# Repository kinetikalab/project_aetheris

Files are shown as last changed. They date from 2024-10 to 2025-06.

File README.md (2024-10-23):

# Project Aetheris
Open source project for plasma water purification

# Water Purification Plasma Chemistry 101

Plasma water purification and activation is a well-known process based on the generation of Reactive Oxygen and Nitrogen Species (RONS) in a plasma discharge, which subsequently oxidize organic impurities and degrade pathogens in water.

## Key Reactions

The basic concept of plasma purification involves the generation of highly reactive species that oxidize organic pollutants and destroy pathogens. Oxidative purification is not a novel concept; it is a well-established technique in water treatment. For example, ozonation and chlorination are well-known oxidative processes used in the water purification industry. While ozone and chlorine are relatively stable, their oxidation potential is limited precisely because of their stability.

In gas discharges, short-lived radicals with excellent oxidation potential can be generated. These radicals are rarely found in nature due to their high reactivity, which results in very short lifespans—on the order of milliseconds or even less.

The hydroxyl radical (OH) has one of the highest oxidation potentials, second only to fluorine, but fortunately, it does not produce toxic by-products. The hydroxyl radical is the most significant species in plasma chemistry, actively oxidizing pollutants and destroying pathogens, and serving as a precursor to other powerful oxygen and nitrogen radicals.

In designing plasma-based water purification technology, we optimized the production of hydroxyl radicals to enhance the efficiency of pollutant oxidation and pathogen destruction.

The hydroxyl radical (OH) plays a critical role in this process. In the literature, the following reaction is often mentioned:

`e + H2O -> OH + H`

However, this reaction requires electron energies greater than **9 eV**, which are rare in atmospheric-pressure gas discharges in air. Additionally, this is a slow reaction. A more efficient way to generate OH is through the following reaction involving excited atomic oxygen:

`e + O2 -> O(1D) + O(3P)`

`H2O + O(1D) -> OH + OH`

`O2 + O(1D) -> O2 + O`

`N2 + O(1D) -> N2 + O`

The dissociation of O₂ is much faster than that of H₂O. After O(1D) is formed, it is a highly reactive species that most likely reacts with N₂, O₂, or H₂O. The balance between H₂O, O₂, and N₂ depends on their concentrations. In dry, cold air, about 90% of O(1D) is lost due to relaxation with N₂ and O₂, but in hot, humid air, around 20% of O(1D) is lost due to relaxation.

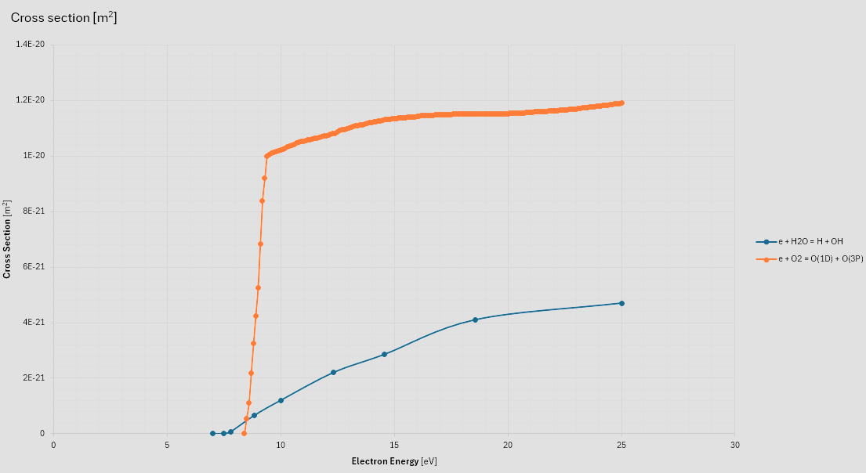
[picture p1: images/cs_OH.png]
Reactions cress sections - **Morgan (Kinema Research & Software)** database and **IST-Lisbon** database, www.lxcat.net, retrieved on Aug 3, 2024.


These reactions are well understood, but the importance of igniting plasma in warm, humid air is often not clearly emphasized in the literature.

## Ozone's Role in Plasma Chemistry

Another critical factor is the presence of ozone (O₃), as it prolongs the lifespan of OH through well-known atmospheric chemistry cycles involving ozone destruction:

`OH + O3 -> O2 + HO2`

`HO2 + O3 -> OH + 2O2`

While these reactions are not particularly fast, ozone is a relative stable molecule and can accumulate in the discharge chamber, reaching high concentrations. Furthermore, HO₂ is a reactive radical that easily dissolves in water, generating hydroxyl radicals in the liquid phase. It plays a significant role in Advanced Oxidation Processes (AOPs) in water.

One crucial aspect that needs attention is the accumulation of NO₂⁻ and NO₃⁻ ions in water treated with plasma. The cyclic synthesis and breakdown of peroxynitrite, with a residual tail of these ions, seems to be a plausible explanation for the phenomenon of Plasma Activated Water (PAW). A more detailed discussion of the synthesis of nitrogen compounds in plasma discharge in water can be found [here](https://onlinelibrary.wiley.com/doi/abs/10.1002/ppap.202000058)

While in some applications—such as sterilization and disinfection in medicine or accelerating plant growth—this fact is a significant advantage, for the production of high-quality drinking water, nitrogen compounds are unacceptable. Therefore, reducing nitrogen concentration is necessary not only to increase ozone levels but also to eliminate residual nitrates and nitrites from the water. However, if we use this technology and reactor for producing water for agriculture, the oxygen filter must be removed from the design.

**Too simple for you?** You can [read more](/discharge_model/glinding_arc_in_ejector_flow.pdf) in the discharge model documentation, where the concept is discussed in greater detail

## In Summary

An ozone-hydroxyl mixture in highly humid air is an excellent combination for mixing with contaminated water.

# Basic Design Principles

1. **Separation of Plasma and Water**  
   It is not necessary to treat contaminated water by directly applying plasma to its surface. This approach is inefficient and difficult to scale. Instead, we generate the ozone-hydroxyl mixture separately and mix it with the water.

2. **Discharge Chamber Design**  
   The most effective method is to feed the discharge chamber with humidified air, then mix the activated air-vapor mixture with the water. An ejector system seems to be the most efficient way to achieve this.

3. **Oxygen and Nitrogen Control**  
   Since ozone is required for higher efficiency, a circulation system during the treatment process is essential. Alternatively, nitrogen should be removed from the water tank at the beginning of the treatment process for better results.

# Overall Device Design

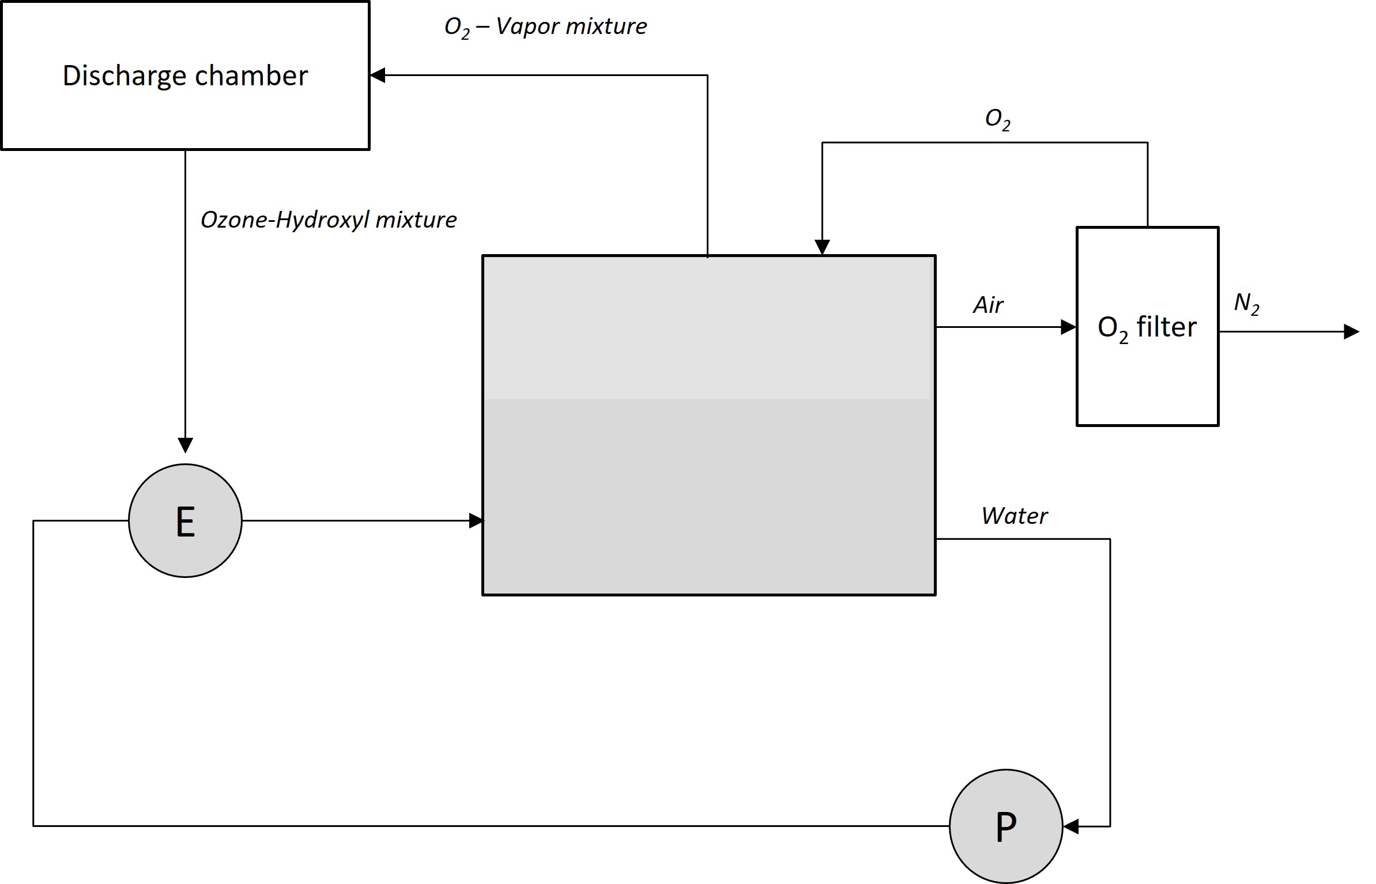
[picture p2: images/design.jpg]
Schematic Design


- **Power Electronics**: See the [power_electronics](./power_electronics/).
- **Discharge Chamber**: See the [discharge_chambers](./discharge_chambers/).
- **Ejector (E)**: For simple ejector models and mixing system dimensions, refer to the [ejector_model](./ejector_model/). Note: the ejector is often combined with the discharge chamber, but these models provide key inputs for the mixing system design.
- **O₂ Filter**: A standard O₂ concentrator with molecular sieves.
  
**Important** Please, read [issues](https://github.com/kinetikalab/project_aetheris/issues) before trying to repeat the design.

# Additional information
2-dimentional gas dicharge model (С parallel code) with plasma-fluid drift-diffusion approximation here [discharge_model](./discharge_model/)

Experimental results are [here](/results) - to be updaded soon (interesting results are coming soon)

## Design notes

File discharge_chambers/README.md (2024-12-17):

# Description

Different designs of discharge chambers:

- [surface_barrier_discharge](./surface_barrier_discharge/): Surface barrier discharge with a spiral electrode.
- [barrier_discharge](./barrier_discharge/): Classical barrier discharge with a set of rods.
- [glinding_arc](./glinding_arc/): Gliding arc ignition in ejector flow
  
- [3d_rotaing_gliding_arc](./glinding_arc/): **FIRST DRAFT** Gliding arc with magnetic rotation, the most promising option.
  
  A couple of words about the rotating arc. Although the rotation of a discharge arc in a magnetic field is not a novel idea, it is quite a cool concept, and here’s why. Achieving uniform plasma in a relatively large volume at atmospheric pressure is the Holy Grail of plasma engineering. Despite the fact that we can't ignite plasma throughout the entire volume, we can force the arc to rotate at a relatively high speed (on the order of kilohertz) and ensure uniform radical generation within the entire discharge chamber. Uniform radical generation leads to excellent mixing with contaminated water, resulting in greater purification efficiency.

- [double_surface_dicharge](./double_surface_discharge/): **Another promising option:** A two-sided surface discharge. Air is drawn through the connection, passing through the outer electrode (a mesh) and then into the ejector chamber where the inner electrode is located. This allows for a two-step activation process, utilizing the full energy of the surface discharge.

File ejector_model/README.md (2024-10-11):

# Ejector model

Sipmle ejector model in based on Sokolov-Zinger model *Sokolov E.Ya. Jet-Stream Apparatuses. Sokolov E.Ya., Zinger N.M. Energoatomizdat, 1968*

Here is the dimentions
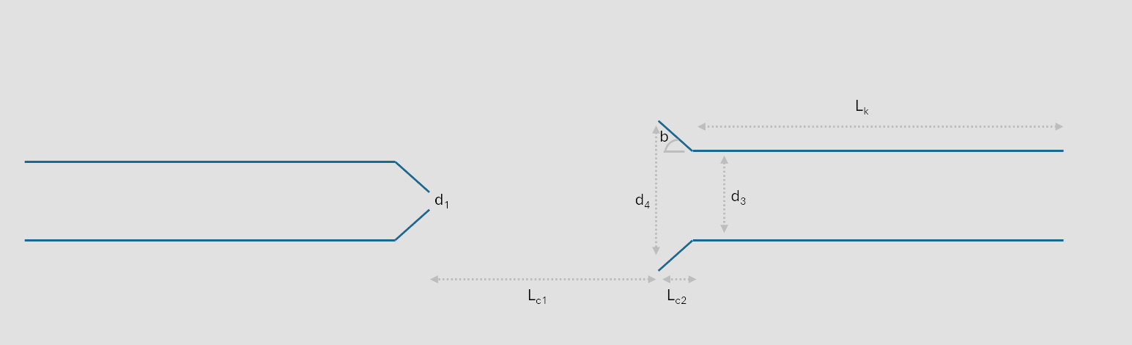
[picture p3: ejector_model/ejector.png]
Ejector dimentions


## Python script
Use python `ejector_model.py` script for dimentions calculations

## Comments

**Designing an ejector (mixing) system involves optimizing two key parameters:**

1. **Air/Water volume ratio** – A higher ratio is better.
2. **Pressure in the discharge chamber** – Lower pressure improves discharge.

However, these two parameters contradict each other, so finding the right balance is the challenge.

**Current Setup:**
- Pressure in the discharge chamber: ~0.5 bar
- Pump: 7-8 bar / 10 L/min – It’s really not easy to find a high-quality pump that can meet these specifications.
- Air/Water volume ratio: 2-3

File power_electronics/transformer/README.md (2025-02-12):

# Description

Design of a high-voltage resonant transformer (L1-L2). See the equivalent circuit diagram in [equivalent_circuit](/power_electronics/equivalent_circuit).

The current coupling coefficient achieved is **k = 0.99**.

- **Secondary winding parasitic capacitance:** 11 pF  
- **Interwinding parasitic capacitance:** 10 pF  

## Design

### Materials Needed

1. Nanocrystal core: [T60006-L2090-W518 Vacuumschmelze](https://eu.mouser.com/ProductDetail/Vacuumschmelze/T60006-L2090-W518?qs=ePbE9GiMmvUhadR4ky1MIg%3D%3D)
2. Coated copper wire: [0.3 mm](https://www.amazon.de/-/en/dp/B09VP9QQGW?ref=ppx_yo2ov_dt_b_fed_asin_title)
3. Housing: [CAD model](/power_electronics/transformer/High-Voltage_Transformer.f3d)
4. Potting compound 
5. Litz wire for primary windings (I used 3x20x0.2 mm wire)

### Process
See transformer design [CAD Model](/power_electronics/transformer/High-Voltage_Transformer.f3d)

**Insulation of the core**

1. Put core intto filling form (do no forget add silcon overaly)
2. Fill the form with potting compound and wait until it cure. 
It is important to avoid core breakdown.

**Secondary windings**

4. Wind the secondary winding using 0.3 mm coated wire, approximately 130 turns.  
   **IMPORTANT:** Maintain a spacing of ~0.2–0.3 mm between turns to minimize parasitic capacitance.
5. Fill the seondary winding with potting compound and wait until it cure.

**Primary windings**

6. Wind 3 primary windings. Refer to the provided 3D model for detailed instructions.

## Comments

1. The T60006-L2090-W518 core is used because it has very low losses and ensures exceptional magnetic permeability. This allows for **fewer turns**, which reduces parasitic capacitance.
2. Litz wire, or even a bundle of Litz wires, is essential due to the high current in the primary windings. It minimizes the skin effect and improves efficiency.
3. Potting compound is critical for insulation to prevent breakdowns between the secondary and primary windings or core breakdown.

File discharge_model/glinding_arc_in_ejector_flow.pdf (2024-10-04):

# GLIDING ARC DISCHARGE MODEL IN EJECTOR FLOW

## Table of Contents

## Problem Statement

We are developing a two-dimensional model of a low-temperature gas discharge powered by a resonant H-bridge.

Several key assumptions are made for this model:

1. The potential difference between the electrodes changes significantly more slowly than the characteristic time for a substantial change in electron energy.
2. The characteristic spatial scale of field variation is much larger than the mean free path of an electron (except within the cathode layer).

These assumptions allow us to assert that the electron energy distribution function depends on the local electromagnetic field, and thus we can employ the drift-diffusion approximation. While this approximation is not valid within the cathode layer, it is fully applicable in the rest of the spatial domain.

The task is reduced to solving the plasma hydrodynamic equations along with Poisson's equation, subject to given boundary conditions.

In the literature on gas discharge modeling, researchers often focus on one specific aspect— either solving the Boltzmann equations under certain approximations or studying and approximating the voltage-current characteristics of the discharge. This specialization, while useful for advancing particular areas of study, often creates a disconnect between the fundamental physics and the practical implementation of discharge systems.

For an engineer or a researcher working on practical solutions, bridging these two domains can be challenging. Understanding how to integrate both the fundamental theoretical aspects and the applied electrical characteristics is crucial for effective system design. In this document, we aim to guide the reader through the complete process of designing and calculating a discharge chamber from the ground up. We will break down each stage step-by-step, from designing and calculating the power circuit to directly modeling the gas discharge itself.

Our goal is to provide a holistic view that connects the theoretical underpinnings with practical engineering decisions, offering an accessible pathway for those looking to combine both aspects in their work.

## Power Supply Configuration

The model assumes a power supply based on a resonant H-bridge circuit (an equivalent circuit is provided here). (https://github.com/kinetikalab/project_aetheris/tree/main/power_electronics/equivalent_circuit)

From a modeling perspective, it is more convenient to work with the T-equivalent circuit of the transformer rather than the transformer itself. The equivalent circuit is shown in Figure 1.

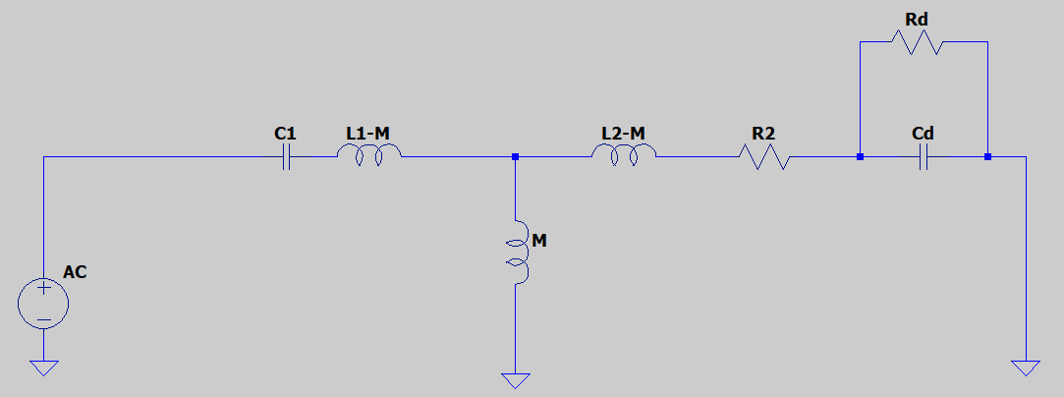
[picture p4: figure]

Figure 1. T-equivalent circuit
M = k√L1L2 – Mutual inductance, with k – being the coupling coefficient, which depends on the coil design.

The coupling coefficient, k, is considered known. In practice, for high-voltage high-frequency transformers, values of k around 0.5 to 0.6 can be easily achieved. Example of high-frequency resonant power transformer can be found here. (https://github.com/kinetikalab/project_aetheris/tree/main/power_electronics/transformer)

It is technically extremely challenging to build a high-voltage transformer with a turns ratio in the hundreds or thousands. Therefore, it is more convenient to work with a resonant circuit, which increases the voltage between the electrodes through both resonance and the turns ratio.

### Resonance Parameter Calculation

Im (Z) = 0 | (1)

where Z – complex impedance

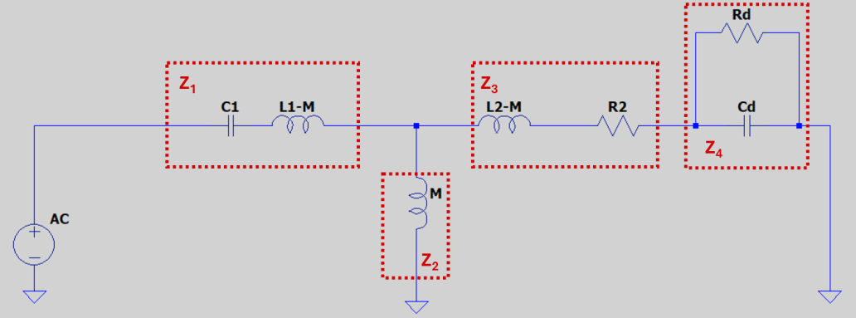
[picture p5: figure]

Z = Z1 +

Z2 ∙ (Z3 + Z4

)
Z2 + Z3 + Z4

Z1 = −

i
ωC1

+ iω(L1 − M)

Z2 = iωM

Z3 = R2 + iω(L2 − M)

Z4 =

−Rd ∙

i
ωCd

⁄
Rd − i
ωCd

⁄

An analytical expression for Z can be derived, but the resulting formulas are quite cumbersome. As can be seen, all parameters are known except for Rd. The resistance of the discharge gap depends on the applied voltage, ranging from infinity (when there is no breakdown) to nearly zero when the discharge transitions to an arc.

To begin, we will analyze the behavior of the circuit under no-load conditions, i.e., in the absence of discharge, where Rd = ∞. Our primary interest is the quality factor Q of the resonant circuit, which indicates how much the voltage is amplified at resonance. By knowing Q, we can easily estimate the amplitude of the voltage across the discharge gap Ud.

Ud = U0 ∙ Q ∙ k ∙ N

Где N = √
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
ω = 2πf, f – switching frequency of the keys (transistors).

Figure 2 shows the result of the quality factor calculation for the following parameters (I have conducted the initial measurements of the future coil and know its characteristics):

C1 = 50 nF

L1 = 1.531 uH

L2 = 1,522 uH

R2 = 0.12 Oℎ

Cd = 1.6 pF

Rd = ∞ Oℎ

k = 0.5

It is customary to express the quality factor in decibels.

Q [db] = 20 ∙ log10Q

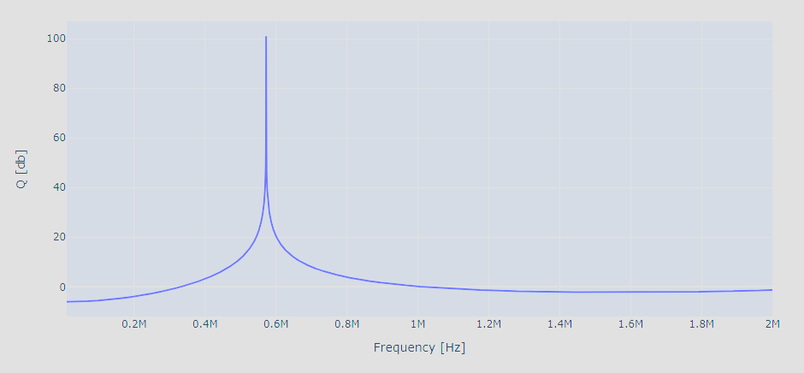
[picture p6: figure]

Fig 2. Quality factor modeling.

The resonant frequencies for the given discharge chamber and coil parameters can be controlled using the balancing capacitor C1. By adjusting C1 it is possible to shift the resonant frequencies to the left or right.

Next, let's examine how Rd affects the behavior of the circuit. Suppose we are operating at the first resonant frequency f1 = 572 kHz. We will analyze how the quality factor depends on Rd.

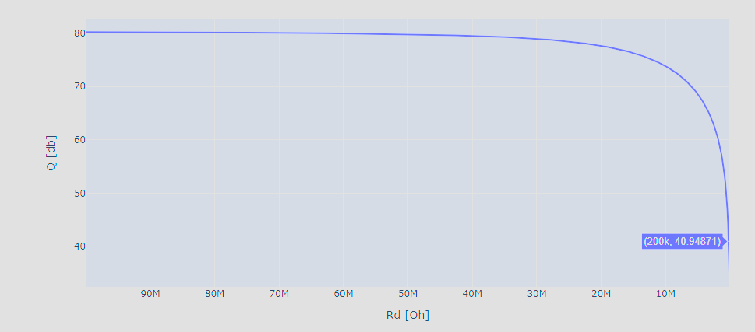
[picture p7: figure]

Fig 3. The dependence of the quality factor at the first resonant frequency on the resistance of the discharge gap.

As can be seen, the quality factor starts to drop significantly only when the resistance is below 10 MΩ, and, for example, at a resistance of ~200 kΩ, it reaches approximately 40 dB (which corresponds to a voltage amplification of ~100 times).

Now, let's try to determine the steady-state active voltage across the discharge gap.

A typical voltage-current characteristic of the gas discharge is shown in Figure 4.

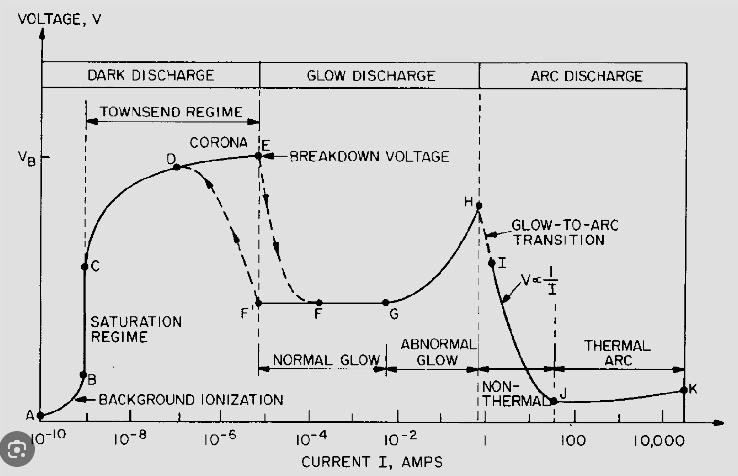
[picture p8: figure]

Figure 4. Qualitative voltage-current characteristic of the gas discharge

At low voltage, the current through the discharge gap is zero. As the breakdown voltage is reached (triggering the electron avalanche), a corona discharge ignites first, which then transitions to a glow discharge, and eventually to an arc. At this point, the resistance drops to very low values, and the discharge can be maintained with relatively low external voltage. This occurs when an arc forms in a localized area, making further spatial propagation of the discharge impossible, as it stabilizes in this narrow spatial zone, and resonant processes are no longer needed to sustain it.

We see that it is not necessary to apply a voltage between the electrodes much higher than the breakdown voltage. This is a crucial observation, as once the breakdown voltage is reached, all the power from the source is used to increase the current (i.e., to sustain and grow the electron avalanche).

In other words, we should maintain the voltage between the electrodes close to the breakdown voltage most of the time.

Consider a discharge chamber with a breakdown voltage of about 15 kV. Geometrically, this corresponds to approximately 5 mm between the electrodes (which is roughly typical setup). Since we want the voltage to exceed the breakdown voltage for most of the period, we will set a target amplitude of 30 kV.

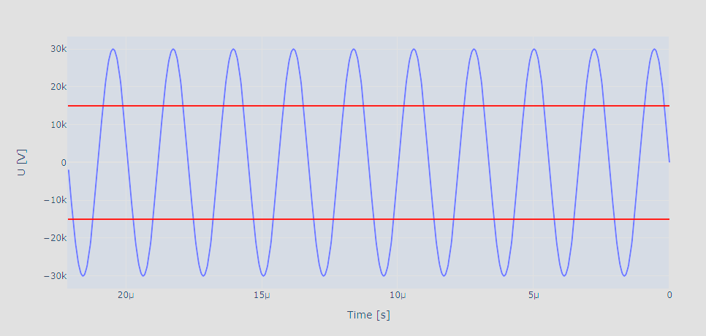
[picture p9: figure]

Assume that the power of the DC source is known and is approximately 500 watts (again, typical for small experimental setups). Let us also assume that other circuit losses are negligible, and all the power from the source is used to sustain the discharge.

P =

Ud

2

2Rd

Thus, the resistance Rd ≈ 200 kΩ, and as can be seen from Figure 3, the quality factor remains high even at this resistance, with the current through the discharge gap being approximately 30-40 mA.

In other words, we observe that under power limitation and high breakdown voltage conditions (tens of kilovolts), the discharge behavior does not affect the resonant frequencies, provided that the discharge does not transition to an arc. If the discharge transitions to an arc, high voltage is no longer required to sustain it, and even a detuning from resonance with a drop in voltage to the hundreds of volts range would be sufficient to maintain the arc.

In practice, this means that the DC source amplitude and the geometry of the discharge gap should be chosen such that:

1. The voltage between the electrodes exceeds the breakdown voltage for most of the period.
2. The discharge chamber design prevents the formation of a stable but geometrically small arc.

If both of these conditions are met, the discharge gap will still have a significant resistance, ensuring that it does not affect the resonant processes of the power circuit.

Let's take a moment to reflect on this point. We have significantly simplified the model by removing the feedback loop between the power electronics and the discharge model. We also recognized the importance of preventing the discharge from transitioning to a stable arc, which can be sustained with relatively low power but is, due to its limited geometry, largely useless for our purposes.

## Discharge Model

Before proceeding to the plasma equations, it is necessary to formulate the problem and clarify some important parameters.

We are modeling a gliding arc discharge. The overall design of the device is shown in Figure 5.

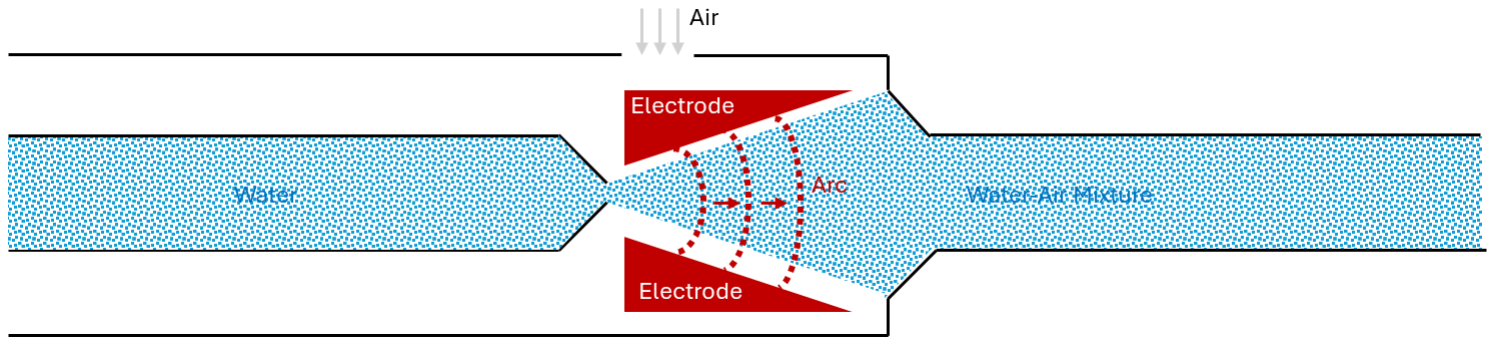
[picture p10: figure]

Figure 5. Gliding Arc in Ejector Flow
Water under pressure pp enters through the ejector nozzle, and due to the narrowing of the nozzle, the water flow velocity increases, creating a region of reduced pressure in the discharge chamber pn, after which it exits into the external environment at pressure pc
. Due to the pressure
difference, air is drawn into the discharge chamber and mixes with the water in a volume ratio of air-to-water ψ . This is a classical water-air ejector setup. All parameters pp, pc

, pn, ψ are
considered known. For details, see ejector model. (https://github.com/kinetikalab/project_aetheris/tree/main/ejector_model)

At the nozzle exit, two electrodes are positioned, supplied with power from the circuit described in the previous chapter. The electrodes are designed in a diverging geometry, meaning the distance between them increases as one moves away from the ejector nozzle.

A few words about the gliding arc discharge:

The gliding arc discharge forms in a system of diverging electrodes. The arc ignites at the narrowest point and moves slowly (at a rate comparable to the medium's velocity) into the expansion zone of the gap between the electrodes (i.e., from left to right in Figure 5). At a certain distance, where the field strength is insufficient to sustain the discharge, the arc extinguishes. Thus, the arc seems to glide between the electrodes in the direction of the medium's flow. Importantly, a gliding discharge only occurs in a moving medium. This means that if the medium between the electrodes is stationary, a gliding discharge will not occur, and we will observe a stationary arc at the point of minimum distance between the electrodes. The mechanism behind the arc's gliding behavior is not fully understood, but it likely involves two factors:

1. The moving medium "disrupts" the stationary arc, imparting some velocity to the electrons and ions in the direction of the medium's movement.
2. The electrode geometry creates a potential gradient in the direction of the electrode divergence.

In other words, we are modeling a discharge in a moving medium consisting of oxygen molecules, nitrogen, vapor, and macro-particles (droplets) of liquid water.

Let's consider the main classes of particles:

1. Electrons
2. Positive ions of oxygen, nitrogen, and water
3. Negative ions of oxygen and water, formed through electron attachment reactions
4. Neutral molecules of oxygen, nitrogen, and water
5. Macro-particles of liquid water

There are practical engineering implementations of water spray into the discharge zone. However, it is important to note that the above setup is quite different from typical spraying. We are dealing with a continuous ejector jet, which, at some distance from the nozzle, begins to break into large droplets due to airflow and turbulent effects. Therefore, we have a medium consisting of very humid air and large (0.5-1 mm in diameter) water droplets in the jet.

Points 1-4 are more or less straightforward and are considered in all hydrodynamic plasma models, so we will focus particularly on the macro-particles of water.

### Influence of Water Droplets

Consider a water droplet of radius rd moving at velocity ug in a medium with concentrations and average energies of electrons and ions, ne

, ε̅e and ni

, ε̅i
, respectively. Let us analyze the processes of absorption and scattering of charged particles by the droplet.

Concentration of Water Droplets and Medium Velocity

Next, we derive the velocity of the medium and the concentration of water molecules. We assume that the volumetric mixing coefficient of air and water ψ , the saturated vapor pressure ps
, the
pressure inside the discharge chamber pn, and the temperature inside the chamber T, are known.

The mass of water in the discharge chamber is given by ρV
1+ψ

, where ρ is the density of water,

and is the V volume of the discharge chamber.

On the other hand, the mass of water in the discharge chamber is equal to the sum of the mass of liquid water droplets and the mass of water in vapor form.

ρV
1+ψ

=

Aw
NA

⏞

Mass of
water molecule
∙

psV
kbT

⏞

Number of
vapor molecules

+ N⏞d Number of droplets

∙

ρVd
Aw

NA

⏞

Number of
molecules
in one drop
Aw
NA

⏞

Mass of
water molecule

NA – Avogadro constant

Vd =

4
3

πrd

3 – water drop volume

From this equation, the concentration of water droplets can be determined.

nd =

Nd
V

=

1
Vd(1+ψ)

−

psAw
NAkbT

1
ρVd

(1)

The concentration of vapor molecules is calculated using the ideal gas equation of state.

ns =

ps
kbT

(2)

Concentration of oxygen and nitrogen molecules

nO2 = 0.21 ∙

pn−ps
kbT

(3)

nN2 = 0.79 ∙

pn−ps
kbT

(4)

Now, let's consider the overall flow pattern of the jet.

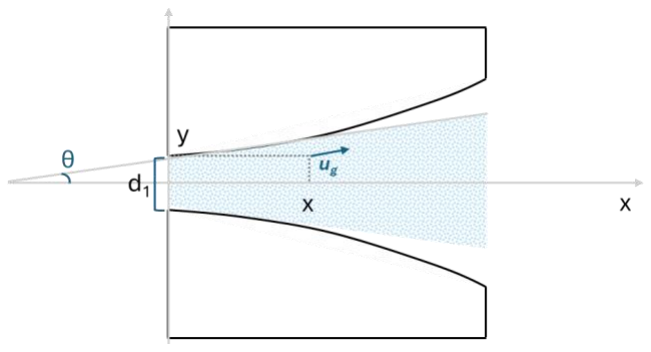
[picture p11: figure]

Fig 6. Ejector water flow

[TBD] Provide a particular solution of the Navier-Stokes equation for a free laminar jet.

Absorption of Electrons and Ions by Water Droplets

A droplet absorbs electrons and ions, acquiring a certain charge. The charge cannot be infinite, as a negatively charged droplet, for instance, will begin to repel electrons and attract ions. The equilibrium charge can be estimated by balancing the fluxes of electrons and ions onto the droplet's surface. We will disregard quantum mechanical tunneling effects and consider a classical approximation. Additionally, we assume that the electron energy distribution follows Maxwellian statistics. In a gas discharge, this is generally not true, but for estimating the droplet charge, the Maxwellian assumption provides acceptable accuracy.

Number of electron absorptions of the drop per unit time:

dNe

d
dt

= ne

- θe

̅̅ ∙ πrd
2
- (1 −

e∙φd
ε̅̅e̅

) e

−

eφd
̅ε̅e̅

⁄

, where υ̅e = √
2ε̅̅e̅
me

– average electron velocity (5)

Let's go through the formula in detail:

ne

- υ̅e

the electron flux multiplied by the absorption cross-section πrd

2

- (1 −

eφd
ε̅̅e̅

), which equals

the droplet's surface area multiplied by the probability of overcoming the Coulomb barrier (1 −

eφd
ε̅̅e̅

),. φd here, is the potential on the droplet surface, and e

−

eφd
ε̅̅e̅

⁄
represents the fraction

of electrons that have energy greater than the Coulomb barrier.

The number of positive ion absorptions by the droplet per unit time:

dNi

d

dt

= ni

- θi

̅ ∙ πrd
2
- (1 +

e∙φd
ε̅i

)

Since ions are attracted to the negatively charged droplet, the sign in the coefficient for overcoming the barrier is reversed, and the Maxwellian distribution exponent is absent.

Let us find the equilibrium potential φd, assuming quasi-neutral plasma where ni = ne .

dNi

d

dt

=

dNe

d
dt
Omitting the mathematical derivation under the assumption that ε̅e ≫ ε̅i and mi ≫ me :

eφd
ε̅̅e̅

~ 1 − e ∙

√
ε̅̅e̅
ε̅i
√
mi
me

⁄ ~1

In other words, the equilibrium potential on the droplet accumulates a very large charge, effectively blocking further electron flux onto the droplet surface due to Coulomb repulsion. Such a result is evident even from simple considerations without requiring mathematical calculations. The average velocity of electrons in non-equilibrium plasma is orders of magnitude higher than that of ions, and therefore, to "balance" the difference in fluxes, the droplet must accumulate a very large charge.

Now, let us estimate how much time is required to reach this equilibrium. Let us return to equation (5).

The potential of the droplet can be expressed in terms of the number of absorbed electrons.

φd =

1
4πε0

Ne

de
rd

Then

dNe

d
dt

= ne

- θe

̅̅ ∙ πrd
2
- (1 −

1
4πε0

Ne

de

2
rdε̅̅e̅

) e

−

1
4πε0

Ne

de
2
rdε̅e̅
(6)

Integrating equation (6) from 0 to Ne

d
(maximum possible charge of the droplet):

Ne

d = Neq

d
- ς, где Neq

d =

4πε0rdε̅̅e̅
e

2

, ς = 1 − e ∙

√
ε̅e̅
εi

̅̅
√
mi
me

We obtain the time required for the droplet to absorb the maximum possible charge.

t = τs ∫

e

u
1−u

du ς
0

, τs =

1
ne∙√
2ε̅e̅
me

∙πrd

2

(7)

Unfortunately, integral (7) can only be solved numerically. To proceed, we will substitute typical energy and concentration values for the gas discharge.

εe
εi

~ 50, εe~ 4 эВ,

mi
me

~ 60 000 (O2 or N2 ions), rd~800 um, ε̅e~ 4 eV

We obtain t~10⁻¹⁹s, which means that a water droplet, upon entering the active discharge zone, absorbs a large charge almost instantaneously, and the absorption cross-section of the droplet can be calculated using the formula:

σd

e−att(εe
, ε̅e

) ≈ πrd

2

- [1 −

ε̅̅e̅
εe

], εe > ε̅e
(8a)

For ions:

σd

i−att(εi
, ε̅e

) ≈ πrd

2

- [1 +

ε̅̅e̅
εi
] | (8b)

For ions, we can directly calculate the average absorption frequency by droplets, assuming a Maxwellian distribution function.

νd

i−att ≈ 2 ∙ rd

2

- √
π
kbTimi
- ε̅e
| (8c)

Elastic Scattering by Water Droplets

Elastic scattering of charges in plasma is derived using Rutherford's formula

σd

el(εe) = 4π ∙ (

Ne

de

2
4πε02εe

)

2
lnΛ | (9)

lnΛ here, is the Coulomb logarithm, obtained by integrating Rutherford's formula over scattering angles related to Debye and Coulomb radii. Generally, without going into details, for plasma it can be considered a dimensionless constant approximately equal to 10-12

Substituting the maximum possible charge into (10), we get:

σd

att = πrd

2

(

ε̅̅e̅
εe

)

2
lnΛ | (10)

Below, we will show that elastic scattering by droplets plays no significant role.

### Collision Integral

Important Note: Below, I break down the simplification of the Boltzmann collision integral step-by-step by integrating it over momentums. There is nothing particularly novel or noteworthy here — this is an entirely standard technique described in all plasma physics textbooks. Anyone who has studied plasma physics has almost certainly done this exercise during lectures or seminars. Below, I provide the standard method of simplifying the collision integral for those who want to refresh their knowledge or are unfamiliar with hydrodynamic plasma modeling. You may skip this part and go directly to the final equations in the last section (but if you are not familiar with the plasma-fluid approximation, skipping this section will make it difficult to understand why the equations of motion are formulated as they are).

In general, the particle distribution function in plasma is described by the Boltzmann equation.

∂f
∂t + θ⃗∇f −

e
me

[E⃗⃗ +

B⃗⃗×θ⃗⃗ c
] ∇θf =
δf
δt | collision | (11)

Before simplifying this rather complicated equation, let's take a closer look at the right-hand side
δf
δt |
collision

, which is referred to as the collision integral.

In general, the collision integral can be expressed as:

δf
δt |
collision

= ∑ Nχk ∫[f(υ

′
) − f(υ)]ω(υ → υ

′
)d

3υ

′
k

Where N is the total concentration of scattering particles, χk is the molar fraction of reactant particles, and is a scalar function ω(υ → υ

′
) representing the probability of transition from state υ to state υ

′
. The relationship between ω(υ → υ

′
) and the reaction cross-section can be expressed as follows:

ω(υ → υ

′
)d

3υ

′ = υ ∙ dσ

We will also use a simple identity (which can be easily derived by swapping indices during integration).

∫φ(υ)[αf(υ

′
) − βf(υ)]ω(υ → υ

′
)d

3υ

′ d

3υ = ∫ f(υ)[αφ(υ

′
) − βφ(υ)]ω(υ → υ

′
)d

3υ

′ d

3υ (12)

Where α, β are some numbers and φ(υ) is a scalar function.

Now, let's return to our problem and consider all possible reactions:

- Ionization
- Attachment
- Elastic scattering
- Inelastic scattering (excitation, dissociation)
- Neutralization

For each type of reaction, we will calculate three moments (integration is carried out over the entire velocity space). These moments will be needed for the hydrodynamic equations of plasma.

M[0] =

1
n

∫

δf
δt |
collision

d

3υ

M[1] =

1
n

∫ υ

δf
δt |
collision

d

3υ

M[2] =

1
n

∫

mυ

2
2

δf
δt |
collision

d

3υ

Ionization

Here and in the following sections, we will assume that the function can be represented as the product of two factors: f(υ, r,t) = n(r,t) ∙ F(υ,t).

This is the first and very important simplification. In the general case, this is quite a strict condition and is not applicable to all plasmas. For this approximation to be valid, the plasma must be in a state close to local thermodynamic equilibrium, with small spatial gradients of external fields and a high collision frequency between particles. As we can see, all these conditions are satisfied in a wide range of gas discharges (how fortunate for us!).

Now let’s calculate moment M[0] using (12)

φ(υ) = φ(υ

′
) = 1, α = 2, β = 1

M[0] = −Nne ∑ χk ∫ F(υ)υσk

ion d
3
k | υ

The integral represents the frequency of collisions leading to ionization. To calculate the integral, one must explicitly know the energy distribution function and the reaction cross-sections. Reaction cross-sections can be found in specialized databases such as LxCat. The energy distribution function, however, is more complex. This topic will be discussed in more detail in the section on the hydrodynamic description of plasma.

Thus

M[0] = Nneν

ion
, где ν

ion = ∑ χk ∫ F(υ)υσk

| ion d
| 3
k | υ

Now let’s calculate M[1]

φ(υ) = φ(υ

′
) = 1, α = 2, β = 1 M[1] = Nne ∑ χk[∫ υ

′υσk

ion d

3υ − ∫ υυσk | ion d
| 3
k | υ]

The first term becomes zero because υ

′
| is isotropic relative to υ, meaning that after ionization,
the electrons scatter isotopically.

M[1] = −Nne ∑χk ∫ υυσk
ion F(υ)d
3υ

k

Let us represent υ = u + δυ, where u is the average electron velocity, and δυ is the thermal random velocity. Assuming local near-thermodynamic equilibrium, δυ is directed isotropically.

So integral over δυ will be zero. Therefore:

M[1] = −uNneν

ion

Let’s calculate M[2]

φ(υ) =

mυ

2
2

,φ(υ

′
) =

mυ

′

2

2

, α = 2, β = 1,

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
= − εion, where εion – ionization energy

M[2] = − εionNneν

ion

Attachment
M[0] = −Nneν

att

M[1] = −uNneν

att

M[2] is a bit difference as election lost all their energy:

φ(υ) =

mυ

2
2

,φ(υ

′
) = 0, α = 0, β = 1

M[2] = − LextNne

where

Lext = ∫

mυ

2
2

υσk

extF(υ) d
3υ – average energy lost due to attachments

Elastic scattering

Let’s calculate M[0]

φ(υ) = φ(υ

′
) = 1, α = 1, β = 1

M[0] = 0

Let’s calculate M[1]

φ(υ) = υ,φ(υ

′
) = υ

′
, α = 1, β = 1

M[1] = Nne ∑ χk[∫ υ

′υ ⋅ dσk

sc(θ) d
3υ − ∫ υυ ⋅ dσk

sc(θ) d
3
k | υ]

Represent υ

′ = υ ∙ cos(θ) + υ⊥where θ – scattering angle. Integral over υ⊥ becomes zero, as we consider isotropic scattering over υ. Again taking into account υ = u + δυ

M[1] = −uNneν

sc

where ν

sc = ∑ χk ∫ υ ⋅ σk

total sc(1 − cos(θ)

̅̅̅̅̅̅̅̅̅)d
3
k | υ , а cos(θ) ̅̅̅̅̅̅̅̅̅ – cosine averaging over the differential
scattering cross section, σk | total sc – total scattering cross section.

Note: Usually in databases and in literature, when data on elastic scattering cross-sections are given, they usually mean σk

total sc(1 − cos(θ)

| ̅̅̅̅̅̅̅̅̅).

Now M[2]

φ(υ) = φ(υ

′
) =

mυ

2
2

, α = 1, β = 1

We neglect energy losses in elastic scattering due to the large mass of molecules and electrons

M[2] = 0

Elastic scattering

Calculating M[0]

φ(υ) = φ(υ

′
) = 1, α = 1, β = 1

M[0] = 0

Now M[1]

Similarly, we assume that for inelastic scattering the remaining velocity scatters isotopically.

M[1] = −uNneν

sc

and M[2]

φ(υ) =

mυ

2
2

,φ(υ

′
) =

mυ

′

2

2

, α = 2, β = 1,

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
= − εext, где εext – excitation energy

M[2] = − εextNneν

ext

Electron-Ion Recombination

For recombination, the electron/ion disappear, so similar to attachment

M[0] = −nine/iν

rec

M[1] = −unine/iν

rec

M[2] = −ε̅e/̅inine/iν

rec

Typically, recombination rates for the ions of interest can be found in reference books or publications.

### Plasma-Fluid and Drift-Diffusion Approximation

Coming back to Boltzmann Equation

∂f
∂t + θ⃗∇f −

e
me

[E⃗⃗ +

B⃗⃗×θ⃗⃗
c

] ∇θf =
δf
δt |
collision

(13)

Equation (13) is not a piece of cake, as f is a seven-dimensional function for each particle species, and the equation itself is both an integral (due to collisions) and a differential equation with two gradients. Solving it directly is challenging or even impossible. Therefore, certain simplifications are used, one of which is the fluid model of plasma. The idea is that for a large class of problems, it is not necessary to know the full velocity distribution function (in case know diffusion and mobility coefficients), but it is enough. Fortunately, our problem falls into this category.

The fluid description of plasma is obtained by integrating equation (13) over velocity space, multiplying by 1,υ, ε, resulting in equations similar to those in hydrodynamics (which is why we spent so much time dealing with collision integrals in the previous chapter). First, we will write them in general form, and then specify them for each particle species.

First momentum – the mass conservation law

∂n
∂t + ∇G = M[0] | (14)

where G = n ∙ u particles flow.

Second momentum – the conservation of momentum law

∂
∂t ∫ fυ⃗ + ∫ fυ⃗ (υ⃗∇f) −

e
me

∫ [E⃗⃗ +

B⃗⃗×υ⃗⃗
c

] ∇υf = M[1]

The calculations for this integral are quite cumbersome, but they are often provided in the literature (for example here), (https://iopscience.iop.org/book/mono/978-0-7503-2360-4/chapter/bk978-0-7503-2360-4ch1) so I will only present the results here, once again assuming local thermodynamic equilibrium.

If we honestly carry out the integration, considering the above assumption, we obtain:

n

du
dt

+ ∇P =

q
m

[E +

B×un
c

] − nN[2ν
ion + ν

sc + ν

ext]

P – pressure tensor.

P = ∫ δυ × δυfd

3υ, δυ × δυ – tensor multiplication

P can be represented as:

P = pI + π, where p – scalar pressure, а π – viscosity tensor

We also assume.

1. Neglecting viscosity
2. u changing very slow, so du
dt

= 0

While the first assumption is fairly straightforward, the second requires a more detailed discussion. In the assumption of near-local thermodynamic equilibrium, the average velocity will be a function of the electromagnetic field strength. This field is, of course, not constant, and as shown in Chapter 1, it varies at a frequency of hundreds of kilohertz. However, the propagation time of the electron avalanche on our scale is tens of nanoseconds, which is orders of magnitude shorter than the frequency of field variation. In other words, during the breakdown process, the field remains nearly unchanged, making the quasi-stationary approximation more than justified.

Thus, pressure becomes:

∇p =

q
m

[En +

B×un
c

] − nuN[2ν
ion + ν

sc + ν

ext]

Also taking into account, that p = nkT and

3. The average temperature in space changes more slowly than the concentration (the same logic as in 2)

∇p = kT∇n

nu = G = −D∇n +

q
|q|

μ [nE +

B×G
c
] | (15a)

D =

kT
νN

, μ =

|q|
mNν
| (15b)

Thus, we have just derived the well-known drift-diffusion approximation, which is commonly presented in the literature on discharge physics.

However, it can be noted that modern approaches (e.g., the "gold standard" for calculating coefficients in gas discharge models — Hagelaar 2005) (https://iopscience.iop.org/article/10.1088/0963-0252/14/4/011) for calculating the coefficients D and μ differ somewhat from those given above. The discrepancy begins with the assumption of local thermodynamic equilibrium. Using the H-theorem, it can be shown that for local thermodynamic equilibrium, the most probable distribution is the Maxwellian distribution with an average velocity u, also known as the local Maxwell-Boltzmann distribution. In other words, formulas (15b) implicitly assume a local Maxwellian distribution of electrons.

Nevertheless, the drift-diffusion approximation can also be derived without the assumption of local thermodynamic equilibrium. Formally, the expression (15a) can be derived only by assuming quasi-stationarity (zeroing out the total time derivative of the average velocity) and the absence of viscosity. However, in such a case, the values of the diffusion and mobility coefficients will no longer be trivial. In particular, Hagelaar 2005 (https://iopscience.iop.org/article/10.1088/0963-0252/14/4/011) explicitly derives these coefficients by solving the Boltzmann equation through an expansion of the distribution function in Legendre polynomials. The difference in the coefficients reaches 10-30%, which is significant. Therefore, we will use data from BOLSIG+ (https://www.bolsig.laplace.univ-tlse.fr/index.html) (a free software based on Hagelaar's 2005 publication) for the drift-diffusion equations.

Someone might ask — why did we struggle through all these formulas for the past few pages if, in the end, we use a slightly different approach? Nonetheless, it was important to show where the hydrodynamic plasma equations fundamentally come from, especially since we derived them without assuming local thermodynamic equilibrium. Furthermore, it was crucial for me to demonstrate the simple physical meaning of the diffusion and mobility coefficients, which is of great value to engineers and experimentalists.

Additionally, the derivations above make the BOLSIG+ program and its output parameters a bit more comprehensible.

Third momentum – the energy conservation law

∂nε̅
∂t + ∇Gε = qEG + ∑ M[2] | (16)

where Gε ≡ n ∫ υεF(υ)d

3υ – energy flux

In the simplest case of local equilibrium (local Maxwell-Boltzmann distribution), the equation for the average energy is simply given by ε̅=

mu

2
2
| , and there is no need to solve equation (16).
However, this approach provides completely unacceptable accuracy for the average energy, so
solving equation (16) is still necessary. To do this, one must determine Gε | . As I mentioned earlier,
deriving it from simple considerations is not possible, as an acceptable level of accuracy is only achieved by accounting for the anisotropy of the distribution function. This is exactly what Hagelaar (2005) does in his paper, providing us with the following equation for the energy flux.

Gε = −Dε∇n +

q
|q|

με

[nE +

B×G
c
] | (17)

Where Dε and με are the energy mobility and diffusion coefficients, which are also output parameters of the BOLSIG+ program.

Final Equations

Now, let's bring all the equations together. Up to this point, we have considered the motion of electrons in a stationary medium, so we will also introduce ug — the velocity of the medium. The velocity ug is 5–6 orders of magnitude lower than the velocity of electron motion in the field, meaning ug only affects the spatial distribution of electrons. We also assume ∇ug~0, as the velocity of the medium changes more slowly in space compared to particle concentrations.

Electrons:

∂ne
∂t + ∇Ge + ug∇ne = Nneν

ion(ε)̅ − Nneν

att(ε)̅ − ∑ ni+ne νrec

e−i
i+ | (ε)̅ + IonRec | (18a)

Ge = −De(ε)̅∇n − μe(ε)̅ [neE +

B×Ge
c
] | (18b)

∂ne,ε
∂t + ∇Ge,ε + ug∇ne,ε = −eEGe − nePe

, Pe = − ∑ M[2]/ne
(18c)

Ge,ε = −De,ε

(ε)̅∇ne,ε − μe,ε(ε)̅[ne,εE +

B×G
c
] | (18d)

ε̅=

ne,ε
ne

(18e)

As seen in equation (18a), there is an additional term, IonRec, which we haven't previously discussed. It is related to the fact that negative ions, when colliding with neutral atoms, can release electrons. In the next section, we will discuss this term in more detail.

Positive ions i +:

∂ni+
∂t + ∇Gi+ + ∇(ni+ug) = Nneνi+

ion − ∑ ni−ni+νrec

ion+−ion−
i− | − Nχdni+νd

i−att(ε̅i
, ε̅e

) + R (19a)

Gi+ = −Di+(ε)(∇ni+)

T + μi+ [ni+E +

B×Gi+
c
] | (19b)

χd – concentration of water droplets

In equation (19a), a new term, R, has appeared—this represents the interaction of ions with neutral particles. In the final vectorized-form equations, we will examine this term in detail.

Negative ions i −:

∂ni−
∂t + ∇Gi− + ∇(ni−ug) = = Nneνi−
att − ∑ | ni−ni+νrec

ion+−ion−
i+=N2

+,O2

+,H2O⁺ | + R | (20а)

Gi− = −Di−(ε)∇n + μi− [ni−E +

B×Gi−
c
] | (20б)

It can be noted that we explicitly account for droplets only for positive ions, but in reality, we also consider them for electrons. This is done by including the droplet absorption cross-sections and their concentration as input parameters when calculating the coefficients in BOLSIG+.

Now, a few words about the data sources. All the electron data is taken from the BOLSIG+ program. For ions, we only need the diffusion and mobility coefficients. The formula for electron mobility is given by Raizer (1987). (https://link.springer.com/book/9783642647604)

μi =

qi
|qi

36√1+
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
- 10⁻⁴ м

2
в∙с

(21)

where

Ai – ion mass

Ag – average mass of medium molecules

(

α
ao

)

3 – dimensionless polarization constant for the gas mixture

p – pressure in the gas chamber in bars (input parameter)

The ion temperature can be determined by the formula

Ti = Tg +

Ai+Ag
5Ai+3Ag

Agma

(μiE)

2
kb

(22)

where

ma = 1.66⁻²⁷ kg – atomic mass

kb – Boltzman constant

The diffusion coefficient can be found using the Einstein relation.

Di = μi

- kbTi
(23)

Analysis of reaction cross-sections

As input parameters, BOLSIG+ uses electron reaction cross-sections, which are typically taken from the public LXCat database. LXCat contains various datasets; I analyzed them all and chose the most comprehensive ones.

So, we use the following data:

Molecule | LXCat DataBase
O2 | IST-Lisbon database
N2 | IST-Lisbon database
H2O | Itikawa database

Below are comparison graphs of reactions with and without droplets.

Input data for the calculation:

- Volume ratio of water/air: u = 2.7
- Average electron energy (needed for droplet cross-section calculation): 3 eV
- Droplet diameter: 400 μm
- Saturated vapor pressure (needed for calculating the concentration of water vapor and liquid droplets): 7,381 Pa
- Pressure in the discharge chamber (needed for calculating the concentration of water vapor and liquid droplets): 55,000 kPa
- Coulomb logarithm: 12

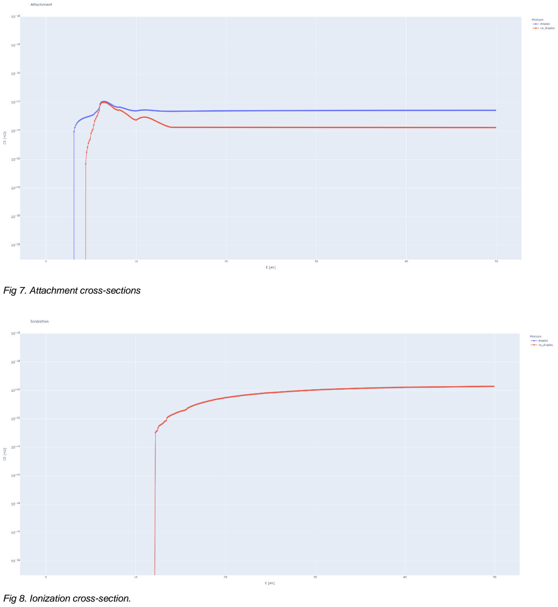
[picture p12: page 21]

Fig 7. Attachment cross-sections

Fig 8. Ionization cross-section.

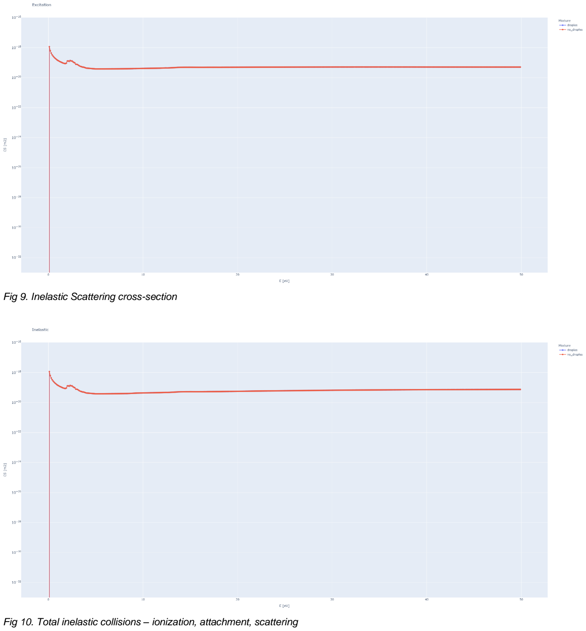
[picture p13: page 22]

Fig 9. Inelastic Scattering cross-section

Fig 10. Total inelastic collisions – ionization, attachment, scattering

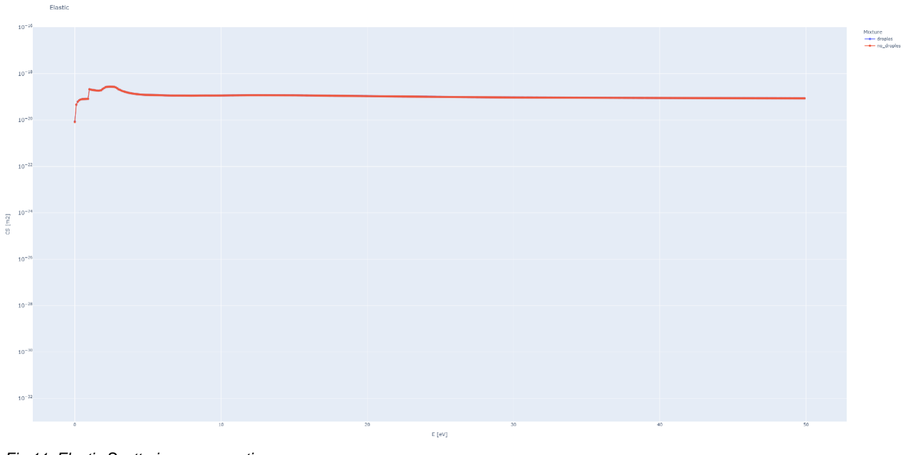
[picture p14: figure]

Fig 11. Elastic Scattering cross section

What can we conclude from these graphs? Significant differences are only observed in attachment reactions, but even with consideration of inelastic reactions, the overall contribution is practically zero (the blue line is not even visible under the red one). In elastic scattering reactions, there are also no differences.

All this suggests that the differences in diffusion and mobility coefficients will be practically negligible. This is indeed the case, as seen in the BOLSIG+ calculations of electron mobility and diffusion coefficients with and without droplets (Figures 12 and 13).

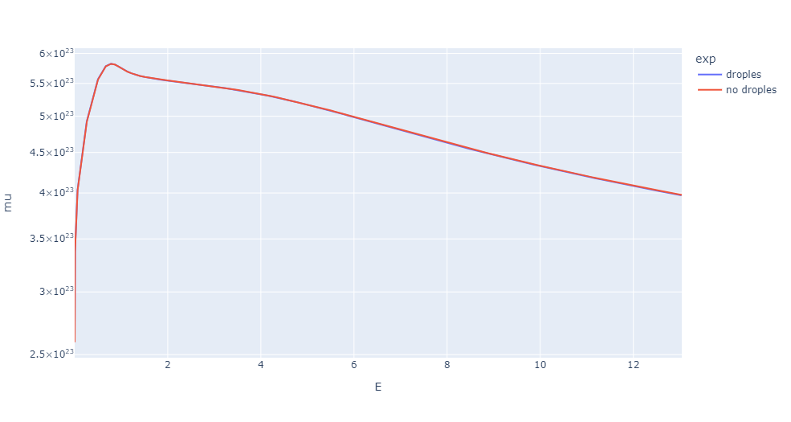
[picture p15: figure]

Fig 12. BOLSIG+ calculations - mobility

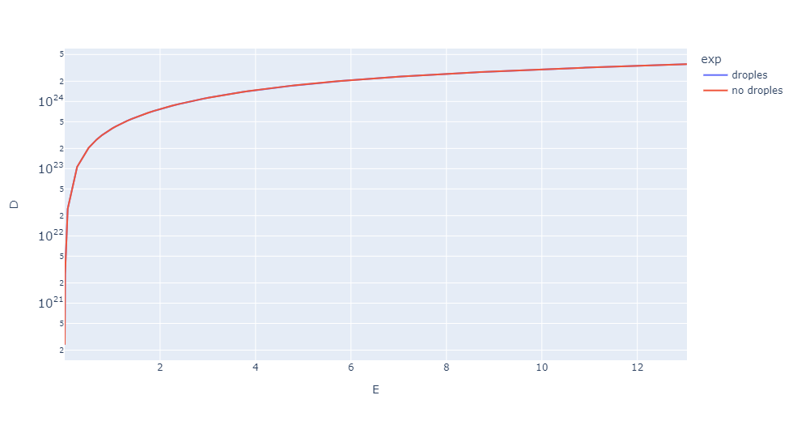
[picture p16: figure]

Fig 13. BOLSIG+ calculations - Diffustion

Thus, the presence of water droplets may affect the electron concentration (we will verify this when we develop the discharge model), but they have virtually no effect on mobility coefficients, diffusion coefficients, or, apparently, the average energy.

### Boundary conditions

In the work Hageelar 2000, (https://journals.aps.org/pre/abstract/10.1103/PhysRevE.62.1452) the boundary conditions for gas discharge problems are carefully derived. Like the authors of the paper, we neglect thermionic emission of electrons, as it is practically zero for electrodes that are not made of special materials taking into account electrode temperature of several hundred kelvins.

Before writing these equations, it is necessary to discuss several important processes.

Field enhancement at the conductor boundary

The surface of a conductor is not perfectly smooth and consists of numerous microcracks and roughness. As a result, the field near the conductor is greatly amplified. Therefore, at the boundary, we will use Ef = FEF ∙ E , where FEF is the Field Enhancement Factor, a dimensionless coefficient that accounts for field enhancement due to surface irregularities. For steel without special polishing, it is typically around 100.

Secondary electron emission

There are two processes of secondary electron emission:

- Thermionic emission: Emission of electrons by conductors heated to high temperatures.
- Secondary emission: Ejection of electrons from the conductor's surface by positive and negative ions.

Thermionic emission can be neglected, as noticeable thermionic emission requires special materials (which, obviously, we do not have).

For estimating secondary emission, the secondary emission coefficient γ is used—a dimensionless parameter that indicates how many electrons are ejected by one ion hitting the conductor's surface. γ depends on the ion's energy or the field strength and is measured experimentally. In our case, considering the FEF, it will be approximately γ ~ 0.1 (Figure 14).

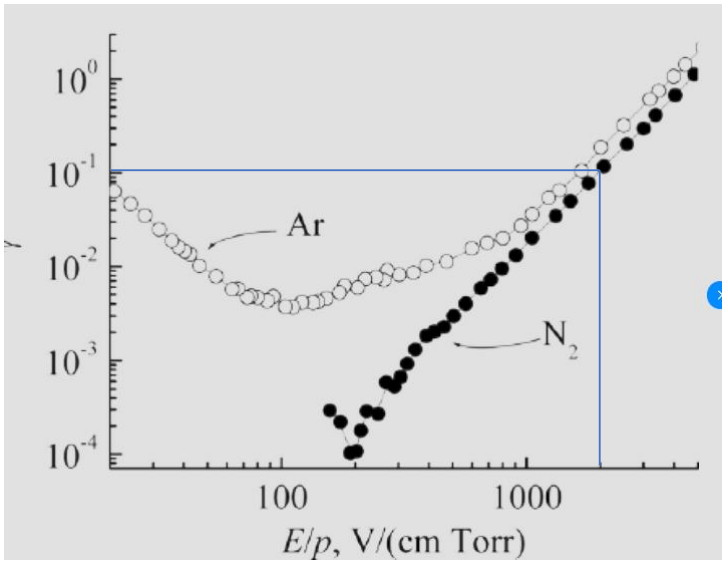
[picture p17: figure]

Fig 14. Secondary emission coefficient

Formal boundary conditions

Hagelaar (https://journals.aps.org/pre/abstract/10.1103/PhysRevE.62.1452) provides the following boundary conditions

Electrons

η ∙ Ge =

1
2

[−(2ae − 1)μeneFEF ∙ E ∙ η +

1
2

υtℎ,ene −

1
2

υtℎ,enγ] − (1 − ae)γ ∑ Gi i
- η

Ions

η ∙ Gi =

1
2

[−(2ai − 1)μiniFEF ∙ E ∙ η +

1
2

υtℎ,ini

]

Where

η – boundary normal vector

υtℎ,e = √
16ε̅̅e̅
3πme

υtℎ,i = √
8kbTi
πAima

ae,i = {

1, | sgn(e, i)E ∙ n > 0
0, | sgn(e, i)E ∙ n ≤ 0

nγ = (1 − ae)

1
μe

γ
2

∑[(2ai − 1) ∙ sgn(qi
) +

1
2

(

8(Ai + Ag)
π(5Ai + 3Ag)

Ag
Ai

)

1/2
]

i

μini

### Final equations for numerical solution

Before writing the final equations, let's discuss an important point regarding heavy particles that we haven't addressed before.

Comment – vectorized equations to be checked for misspelling and mistakes

Vectorization of equations for heavy particles

In a discharge involving water vapor, many types of ions are produced—approximately 23 types. Only six of them are formed directly due to attachment and ionization reactions. The rest are generated when ions collide with neutral particles, forming new classes of ions. For example, N2

+ + O → NO⁺ + N(2D), and there are many such reactions.

Moreover, in plasma discharge, a large number of new neutral particles are generated, which are of great interest. For instance, N(2D) + H2O → NH + OH. Ideally, we would also include these in the model. After all, the concentrations of chemically active radicals are the main focus of all calculations. Fortunately, the reaction rates for all these processes are known and do not require additional calculations. All of this suggests that it would be beneficial to extend equations (19,20) to neutral particles and rewrite them in a unified matrix form for all classes of heavy particles, which is not very difficult.

Another point is that, given the large number of particles, the problem becomes quite resource-intensive. Additional complexity will be introduced by the term B×G
c

, which will require additional iterations at each step of the flux calculation. Therefore, to simplify the problem, we assume B = 0

Now, let us define:

n – n × 1 vector representing the concentrations of all heavy particles, including positive ions, negative ions, and chemical radicals. The dimension of vector n is the number of heavy particles considered in the model.

D – an n × 1 vector containing the diffusion coefficients. The diffusion coefficient for ions is calculated using formula (21), while for neutral particles, the diffusion is equal to

Dm =

1
3√2nmσm

√
8kbT
πmm

σ = π(rm

2 + rg

2
)

rm, rg – effective radii of radicals and molecules

nm – particles concentration

mm = Amma – heavy particle mass (Am- molar mass, ma = 1.66⁻²⁷ kg atomic mass)

T – environment temperature

The vector is tied to the computational grid because D depends on the ion temperature, which in turn depends on the field strength.

μ – an n × 1 mobility vector. The mobility for ions is calculated using formula (21), while for neutral particles, it is equal to 0. This vector is constant and is calculated once.

∇n – gradient matrix n × 2, (∇n)i,j =

∂ni
∂xj

Z – an n × 1 charge vector, representing the values of elementary charges for ions and 0 for neutral particles.

Zabs – an n × 1 charge vector, representing binary values of particles: 1 if the particle is an ion and 0 if it is neutral.

⊙ – element-wise multiplication

R

e
(ε̅e) – An n × n matrix containing the reaction rates for interactions between electrons, ions, and neutral atoms. It includes all ionization, attachment, excitation, elastic collision, and neutralization coefficients. Some reactions depend on the average electron energy, meaning we will technically have a set of such matrices for each average electron energy. Most of the information in this matrix is obtained from the results of BOLSIG+.

The situation is more complex with interactions between particles themselves. For example, N2

+ + O → NO⁺ + N(2D). Fully linearizing such a system is not feasible, so we will use a few tricks.

First, we introduce the stoichiometric matrix S

rec of dimensions n × r, where r - is the number of reactions. Each column represents a reaction, with +1 or +2 or -1 indicating the addition or depletion of the corresponding particle from the respective row as a result of the reaction.

Second, we now need to link this matrix with the concentrations of the particles and the reaction constant (the reaction constant has units of m³
s

−1
; by multiplying it by the concentrations, we obtain units of m⁻³
s

−1
, i.e., the rate of change in the number of particles per unit time). Thus, we need two factors—the reaction constants and the product of two concentrations ninj
. In other
words, Krec ⊙ Nrec, where Krec is an r × 1 vector consisting of reaction constants, and Nrec is a vector consisting of the products ninj
for the reacting particles.

Comments for efficient computations: I suggest introducing and storing this information in a vector structure ξ

k = {i,j}

k
, indicating which particles are involved in each reaction. Then we can redefine the multiplication function as ξ ∗ n ≡ {ninj

}.

Thus, the reaction rate vector can be written as Krec ⊙ (ξ ∗ n), and the change in concentration as S

rec ∙ (Krec ⊙ (ξ ∗ n)).

Now, let's write the reactions for heavy particles in vectorized form

∂n
∂t + G ∙ ∇ + ∇n ∙ ug = nenR

e
(ε̅e

) + S

rec ∙ (Krec ⊙ (ξ ∗ n))

G = −D(E) ⊙ ∇n + μ ⊙ (n ∙ E

T
)

Such a vector form will also affect the equations for electrons, specifically in terms of electron neutralization by ions and electron production due to collisions of ions with neutral atoms.

Therefore, we need two more matrices:

RNEU

e
(ε̅e) – an n × 1 vector containing the rates of electron neutralization reactions by heavy particles (obviously, for negative ions and neutral atoms, the values will be zero). This vector is tied to the computational grid.

Re

s – an n × n matrix responsible for electron production due to interactions of ions with neutral molecules. {Re

s
}i,j = ki,j
, where ki,j

is the reaction constant for particle i interacting with particle j, resulting in electron emission.

Final vectorized equations

The geometry of the problem is shown in Figure 15.

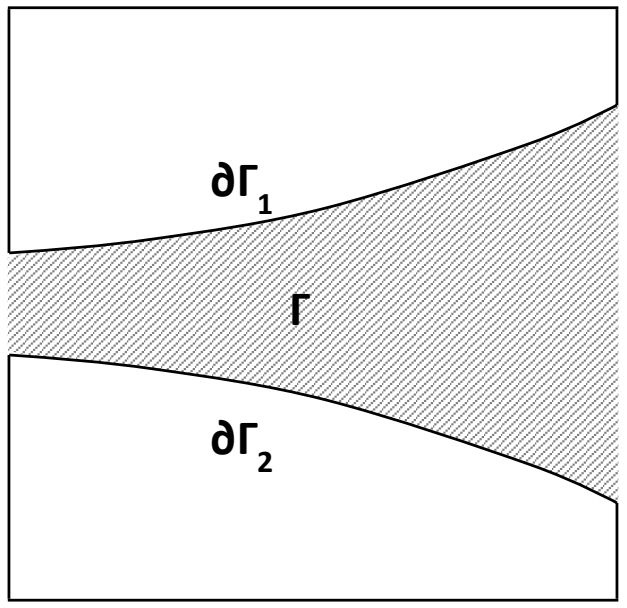
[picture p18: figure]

Fig 15. Problem geometry
A two-dimensional problem solved in the domain Γ with boundary conditions on the boundaries ∂Γ1, ∂Γ2.

Electrons

∂ne
∂t + ∇Ge + ug∇ne = Nneν

ion(ε)̅ − Nneν

att(ε)̅ − nen

TRNEU

e
(ε̅e

) + n

TRe

sn | (24a)

Ge = −De(ε̅e)∇ne − μe(ε̅e

̅ )neE | (24b)

∂ne,ε
∂t + ∇Ge,ε + ug∇ne,ε = −eEGe − nePe
(24c)

Ge,ε = −De,ε

(ε̅e

)∇ne,ε − μe,ε(ε̅e)ne,εE | (24d)

ε̅=

ne,ε
ne

(24e)

RNEU

e
(ε̅e

), Re

s
, De

(ε̅e

), μe

(ε̅e

̅ ),De,ε
(ε̅e

), μe,ε(ε̅e) – input parameters based

ug – Input parameter: we know the velocity of the medium at each point of the grid

Heavy Particles

∂n
∂t + G ∙ ∇ + ug ⊙ ∇n = neR

e
(ε̅e

) + S

rec ∙ (Krec ⊙ (ξ ∗ n)) | (25a)

G = −D(E) ⊙ ∇n + μ ⊙ (n ∙ E

T
) | (25b)

D(E)i = {
μi
- kbTi

, Ti = T +

Ai+Ag
5Ai+3Ag

Agma

(μiE)

2
kb

, i − ion

1
3√2Nπ(ri

2+rg
2
)

√
8kbT
πAima

, i − neutral molecule

(25c)

μi = Zi

36√1+
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
- 10⁻⁴
, Zi − particle′s cℎarge | (25d)

R

e
(ε̅e

), S

rec

, Krec
, ξ , rg, Ai

, ri – input parameters

ug – Input parameter: we know the velocity of the medium at each point of the grid

N – total particles concentration (depends on pressure in discharge chamber) – input parameter

Poisson equation

∆φ = −

e
ε0

[−ne + Z

Tn] | (26a)
E = −∇φ | (26b)

φ = 0|∂Γ1

φ = U0 sin ωt|∂Γ2

Boundary conditions (∂Γ1, ∂Γ2)

η ∙ Ge =

1
2

[−(2ae − 1)μeneE ∙ η +

1
2

υtℎ,ene −

1
2

υtℎ,enγ] − (1 − ae
)γ(Zabs

T
- G) ∙ η | (27a)

η ∙ Ge,ε =

1
2

[−(2ae − 1)μe,εne,εE ∙ η +

1
2

υtℎ,ene,ε −

1
2

υtℎ,enγ,ε

] | (27b)

G ∙ η =

1
2

[−(2α − 1) ⊙ abs(μ) ⊙ n ∙ (E ∙ η) +

1
2
Vtℎ ⊙ n] | (27c)

Where

nγ = (1 − ae

)

1
μe

γ
2
- [ ((2α − 1) ⊙ μ)

T
- n + (β ⊙ abs(μ))

T
- n]

αi = {

1, sign(Zi

) ∙ (E ∙ η) > 0
0, sign(Zi

) ∙ (E ∙ η) ≤ 0

βi = {

1
2

(

8(Ai + Ag)
π(5Ai + 3Ag)

Ag
Ai

)

1/2
, Zi

! = 0

0, | Zi = 0

ae = {

1, | −E ∙ n > 0
0, | −E ∙ n ≤ 0

υtℎ,e = √
16ε̅̅e̅
3πme

Vtℎ =
{

√
8kbTi
πAima

, Ti = T +

Ai + Ag
5Ai + 3Ag

Agma

(μiE)

2
kb

, i − ion
√
8kbTi
πAima

, Ti = T, i − neutral particle

γ, Zabs

T
,Ag - input parameter

### Numerical solution

Coming soon …

Finite difference scheme

Coming soon …

Reaction database and input matrix calculations

Coming soon …

Code optimization and parallelization

Coming soon …

How to use code

Coming soon …

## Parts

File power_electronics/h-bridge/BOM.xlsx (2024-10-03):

Part Number: |  |  |  |  |  | Date:
Rev: |  | 01 |  |  |  | 2021 May 25
Associated Board: |  | HFPB_01-PCB
Description: |  | High Frequency Power Bridge HFPB. Bill of materials |  |  |  | Moscow
Item | Reference | Part number | D Sh | Vendor | Package/case | Description | Quant per 1 PCB | Price per 1p (Mous. for rus) | Total cost | Comment | Digi-key | Mouser | Other distributors
 | I n t e g r a t e d c i r c u i t
1 | U1 | TSR 1-24120 | D (https://www.tracopower.com/sites/default/files/products/datasheets/tsr1_datasheet.pdf) | Traco | SIP-3 | DC/DC Converter, Non-Iso, Uout=12V, Iout=1A | 1 | 8.67 | 8.670 |  | 1951-2739-ND (https://www.digikey.com/en/products/detail/traco-power/TSR-1-24120/9383773) | 495-TSR-1-24120 (https://ru.mouser.com/ProductDetail/TRACO-Power/TSR-1-24120?qs=ckJk83FOD0XFyuKFnkiJHw%3D%3D) | Elitan (https://www.elitan.ru/price/index.php?find=TSR1-24120&delay=-1&mfg=all&seenform=y)
2 | U2 | TSR 1-2450 | D (https://www.tracopower.com/sites/default/files/products/datasheets/tsr1_datasheet.pdf) | Traco | SIP-3 | DC/DC Converter, Non-Iso, Uout=5.0V, Iout=1A | 1 | 8.67 | 8.670 |  | 1951-2747-ND (https://www.digikey.com/en/products/detail/traco-power/TSR-1-2450/9383780) | 495-TSR-1-2450 (https://ru.mouser.com/ProductDetail/TRACO-Power/TSR-1-2450?qs=ckJk83FOD0XFKqda0Mzkgw%3D%3D) | Elitan (https://www.elitan.ru/price/index.php?find=TSR1-2450&delay=-1&mfg=all&seenform=y)
3 | U3 | LD39050PU33R | D (https://www.st.com/content/ccc/resource/technical/document/datasheet/12/43/cc/93/21/f6/41/66/CD00227527.pdf/files/CD00227527.pdf/jcr:content/translations/en.C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) | STM | DFN-6 | LDO 3.3V 500mA | 1 | 1.87 | 1.870 |  | 497-8716-1-ND (https://www.digikey.com/en/products/detail/stmicroelectronics/LD39050PU33R/2039876) | 511-LD39050PU33R (https://ru.mouser.com/ProductDetail/STMicroelectronics/LD39050PU33R) | Elitan (https://www.elitan.ru/price/index.php?find=LD39050PU33R&delay=-1&mfg=all&seenform=y)
4 | U4 | STM32F334R8T7 | D (https://www.st.com/content/ccc/resource/technical/document/datasheet/d1/cd/3d/18/a2/2c/4e/d0/DM00097745.pdf/files/DM00097745.pdf/jcr:content/translations/en.D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) | STM | LQFP-64 | ARM Cortex-M4 STM32F3 IC 32-Bit 72MHz 64KB | 1 | 11.62 | 11.620 |  | 497-18933-ND (https://www.digikey.com/en/products/detail/stmicroelectronics/STM32F334R8T7/5268274) | 511-STM32F334R8T7 (https://ru.mouser.com/ProductDetail/STMicroelectronics/STM32F334R8T7?qs=9MuLHSklicpmYDk0V9oFMQ%3D%3D) | Elitan (https://www.elitan.ru/price/index.php?find=STM32F334R8T7&delay=-1&mfg=all&seenform=y)
5 | U5 | AD8628AUJZ | D (https://www.analog.com/media/en/technical-documentation/data-sheets/AD8628_8629_8630.pdf) | Analog | TSOT23-5 | OpAmp Rail-to-Rail 1 Channel | 1 | 4.27 | 4.270 |  | AD8628AUJZ-REEL7CT-ND (https://www.digikey.com/en/products/detail/analog-devices-inc/AD8628AUJZ-REEL7/996267) | 584-AD8628AUJZ-R7 (https://ru.mouser.com/ProductDetail/Analog-Devices/AD8628AUJZ-REEL7?qs=%2FtpEQrCGXCwiRJmva1wT4g%3D%3D) | Elitan (https://www.elitan.ru/price/index.php?find=AD8628AUJZ&delay=-1&mfg=all&seenform=y)
6 | U6 | CP2102-GM | D (https://www.silabs.com/documents/public/data-sheets/CP2102-9.pdf) | Silicon Labs | QFN-28 | Interface USB to UART | 1 | 5.13 | 5.130 |  | 336-1160-5-ND (https://www.digikey.com/en/products/detail/silicon-labs/CP2102-GM/696598) | 634-CP2102-GM (https://ru.mouser.com/ProductDetail/Silicon-Labs/CP2102-GM?qs=yHCtFi5ROqJvCcyR88R4Pg%3D%3D) | Elitan (https://www.elitan.ru/price/index.php?find=CP2102-GM&delay=-1&mfg=all&seenform=y)
7 | U7 | ISO1540D | D (https://www.ti.com/lit/ds/symlink/iso1540-q1.pdf?ts=1615839581838) | Silicon Labs | SOIC-8 | Digital Isolator I2C 2500Vrms 2 Channel 1Mbps | 1 | 9.29 | 9.290 |  | 296-34896-5-ND (https://www.digikey.com/en/products/detail/texas-instruments/ISO1540D/3601070) | 595-ISO1540D (https://ru.mouser.com/ProductDetail/Texas-Instruments/ISO1540D?qs=rg6Iqu58vpWvO86XnJi3%2Fg%3D%3D) | Elitan (https://www.elitan.ru/price/index.php?find=ISO1540D&delay=-1&mfg=all&seenform=y)
8 | U8, U11, U20, U21 | EC4SAW-24S15N | D (https://www.cincon.com/productdownload/SPEC-EC4SAW-V12.pdf,%20https:/www.cincon.com/productdownload/EC4SAW-SERIES-application-note.pdf) | Cincon | SIP-8 | DC/DC Converter 6W 1.5kV Isolated | 4 | 18.61 | 74.440 |  | EC4SAW-24S15N (https://www.digikey.com/en/products/detail/cincon-electronics-co-ltd/EC4SAW-24S15N/9683268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) | 418-EC4SAW-24S15N (https://ru.mouser.com/ProductDetail/Cincon/EC4SAW-24S15N) | Elitan (https://www.elitan.ru/price/index.php?find=EC4SAW-24S15N&delay=-1&mfg=all&seenform=y)
9 | U9, U10, U22, U23 | TPS71550DCKR | D (https://www.ti.com/lit/ds/symlink/tps715.pdf?HQS=dis-dk-null-digikeymode-dsf-pf-null-wwe&ts=1615331244877) | Texas | SC70-5 | LDO 3.3V 50mA | 4 | 1.2 | 4.800 |  | 296-15046-1-ND (https://www.digikey.com/en/products/detail/texas-instruments/TPS71550DCKR/562815) | 595-TPS71550DCKR (https://ru.mouser.com/ProductDetail/Texas-Instruments/TPS71550DCKR?qs=Gse6rAGbi7%252BvaZj1yCtdfw%3D%3D) | Elitan (https://www.elitan.ru/price/index.php?find=TPS71550DCKR&delay=-1&mfg=all&seenform=y)
10 | U12, U13, U16, U17 | SI8620BC-B-ISR | D (https://www.silabs.com/documents/public/data-sheets/si861x-2x-datasheet.pdf) | Silicon Labs | SOIC-8 | Digital Isolator 3750Vrms 2 Channel 150Mbps | 4 | 2.01 | 8.040 |  | 336-4330-1-ND (https://www.digikey.com/en/products/detail/silicon-labs/SI8620BC-B-ISR/4069784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) | 634-SI8620BC-B-ISR (https://ru.mouser.com/ProductDetail/Silicon-Labs/SI8620BC-B-ISR) | Elitan (https://www.elitan.ru/price/index.php?find=SI8620&delay=-1&mfg=all&seenform=y)
11 | U14, U15, U18, U19 | IXDD614YI | D (https://www.ixysic.com/home/pdfs.nsf/0/18AB54BEE23C4E71852577520051C399/$file/IXD_614.pdf) | IXYS | TO263-5 | MOSFET Driver IC | 4 | 8.85 | 35.400 |  | CLA338-ND (https://www.digikey.com/en/products/detail/ixys-integrated-circuits-division/IXDD614YI/2391600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) | 849-IXDD614YI (https://ru.mouser.com/ProductDetail/IXYS-Integrated-Circuits/IXDD614YI/) | Elitan (https://www.elitan.ru/price/index.php?find=IXDD614YI&delay=-1&mfg=all&seenform=y)
 | Alternative | IXDD630YI | D (https://www.ixysic.com/home/pdfs.nsf/0/6AC7CC624179BDA185257873005D6BE4/$file/IXD_630.pdf) | IXYS | TO263-5 | MOSFET Driver IC | 4 | 13.5 |  |  | CLA375-ND (https://www.digikey.com/en/products/detail/ixys-integrated-circuits-division/IXDD630YI/2623251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) | 849-IXDD630YI (https://ru.mouser.com/ProductDetail/IXYS-Integrated-Circuits/IXDD630YI?qs=uhAJVUz%252BE38ko%2Fiwob07zA%3D%3D)
 | I n d u c t o r s
12 | FB1-FB17 | MPZ1608S601ATA00 | D (https://product.tdk.com/info/en/catalog/datasheets/beads_commercial_power_mpz1608_en.pdf) | TDK | SMD0603 | Ferrite Bead 600Ohms 1A 150mOhm | 17 | 0.163 | 2.771 |  | 445-2205-1-ND (https://www.digikey.com/product-detail/en/tdk-corporation/MPZ1608S601ATA00/445-2205-1-ND/765103) | 810-MPZ1608S601ATA00 (https://ru.mouser.com/ProductDetail/TDK/MPZ1608S601ATA00)
13 | L1, L2, L3, L4 | DLW5BTM142TQ2L | D (https://www.murata.com/en-us/products/productdata/8796761587742/EFLC0025.pdf) | Murata | SMD-4 | Common Mode Choke 2 lines 1.4kOhm 2A 56mOhm | 4 | 2.16 | 8.640 |  | 490-11110-1-ND (https://www.digikey.com/en/products/detail/murata-electronics/DLW5BTM142TQ2L/4421377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) | 81-DLW5BTM142TQ2L (https://ru.mouser.com/ProductDetail/Murata-Electronics/DLW5BTM142TQ2L?qs=eTNEoJdcnEJfMtnluA8TOg%3D%3D)
 | L E D s
14 | LD1 | LTST-C193KGKT-5A | D (http://optoelectronics.liteon.com/upload/download/DS22-2007-0094/LTST-C193KGKT-5A.PDF) | Lite-On Inc. | SMD0603 | LED Green 5mA 572nm Vf=2.0V (≈) | 1 | 0.632 | 0.632 |  | 160-1828-1-ND (https://www.digikey.com/product-detail/en/lite-on-inc/LTST-C193KGKT-5A/160-1828-1-ND/2356247) | 859-LTSTC193KGKT5A (https://ru.mouser.com/ProductDetail/Lite-On/LTST-C193KGKT-5A)
15 | LD2, LD5, LD6 | LTST-C193KSKT-5A | D (https://optoelectronics.liteon.com/upload/download/DS22-2004-141/LTST-C193KSKT-5A.PDF) | Lite-On Inc. | SMD0603 | LED Yellow 5mA 591nm Vf=2.0V (≈) | 3 | 0.632 | 1.896 |  | 160-1831-1-ND (https://www.digikey.com/en/products/detail/lite-on-inc/LTST-C193KSKT-5A/2356245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) | 859-LTSTC193KSKT5A (https://ru.mouser.com/ProductDetail/Lite-On/LTST-C193KSKT-5A)
16 | LD3 | LTST-C194KFKT | D (https://optoelectronics.liteon.com/upload/download/DS22-2010-0196/LTST-C194KFKT.PDF) | Lite-On Inc. | SMD0603 | LED Orange 5mA 605nm Vf=2.0V (≈) | 1 | 0.632 | 0.632 |  | 160-1833-1-ND (https://www.digikey.com/en/products/detail/lite-on-inc/LTST-C194KFKT/2356222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) | 859-LTST-C194KFKT (https://ru.mouser.com/ProductDetail/Lite-On/LTST-C194KFKT)
17 | LD4 | LTST-C193KRKT-5A | D | Lite-On Inc. | SMD0603 | LED Red 5mA 631nm Vf=2.0V (≈) | 1 | 0.632 | 0.632 |  | 160-1830-1-ND (https://www.digikey.com/en/products/detail/lite-on-inc/LTST-C193KRKT-5A/2356244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) | 859-LTSTC193KRKT5A (https://ru.mouser.com/ProductDetail/Lite-On/LTST-C193KRKT-5A)
 | D i o d e s
18 | D1, D7, D10, D11, D14, D15 | BAT54J,115 | D (https://rocelec.widen.net/view/pdf/es9ugfukaw/PHGLS14913-1.pdf?t.download=true&u=5oefqw) | Nexperia | SOD-323F | Diode Schottky 30V 0.2A | 6 | 0.567 | 3.402 |  | 1727-4818-1-ND (https://www.digikey.com/en/products/detail/nexperia-usa-inc/BAT54J-115/1692654) | 771-BAT54J115 (https://ru.mouser.com/ProductDetail/Nexperia/BAT54J115)
19 | D2, D12, D13, D16, D17 | MBRS540T3G | D (https://www.onsemi.com/pdf/datasheet/mbrs540t3-d.pdf) | ON Semi | SMC | Diode Schottky 40V 5A | 5 | 0.94 | 4.700 |  | MBRS540T3GOSCT-ND (https://www.digikey.com/en/products/detail/on-semiconductor/MBRS540T3G/918647) | 863-MBRS540T3G (https://ru.mouser.com/ProductDetail/ON-Semiconductor/MBRS540T3G)
20 | D3, D4 | BAT60JFILM | D (https://www.st.com/content/ccc/resource/technical/document/datasheet/3d/d2/27/1d/20/e3/4d/48/CD00001944.pdf/files/CD00001944.pdf/jcr:content/translations/en.C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) | STM | SOD-323 | Diode Schottky 10V 3A | 2 | 0.649 | 1.298 |  | 497-3707-1-ND (https://www.digikey.com/en/products/detail/stmicroelectronics/BAT60JFILM/686386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) | 511-BAT60JFILM (https://ru.mouser.com/ProductDetail/STMicroelectronics/BAT60JFILM)
21 | D5, D6, D8 | D1213A-01T-7 | D (https://www.diodes.com/assets/Datasheets/D1213A-01T.pdf) | Diodes Inc. | SOD-523 | TVS Diode Vstand=5.5V Vclamp=10V | 3 | 0.617 | 1.851 |  | D1213A-01T-7DICT-ND (https://www.digikey.com/en/products/detail/diodes-incorporated/d1213a-01t-7/3340396) | 621-D1213A-01T-7 (https://ru.mouser.com/ProductDetail/Diodes-Incorporated/D1213A-01T-7)
22 | D9 | TPD2E001DZDR | D (https://www.ti.com/lit/ds/symlink/tpd2e001.pdf?HQS=dis-dk-null-digikeymode-dsf-pf-null-wwe&ts=1616116107965) | Texas | SOP-4 | TVS Diode Vstand=5.5V Vbr=11V | 1 | 1.02 | 1.020 |  | 296-24770-1-ND (https://www.digikey.com/en/products/detail/texas-instruments/TPD2E001DZDR/1907454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) | 595-TPD2E001DZDR (https://ru.mouser.com/ProductDetail/Texas-Instruments/TPD2E001DZDR)
 | B u z z e r
23 | LS1 | CMI-9605IC-0580T | D (https://www.mouser.fi/datasheet/2/670/cmi-9605ic-0580t-1777058.pdf) | CUI | Thr.holes 9.6x5.0 | Buzzer Magnetic 5V 80dB 2.7kHz | 1 | 2.28 | 2.280 |  | 2223-CMI-9605IC-0580T-ND (https://www.digikey.com/product-detail/en/cui-devices/CMI-9605IC-0580T/2223-CMI-9605IC-0580T-ND/11674175) | 490-CMI-9605IC-0580T (https://ru.mouser.com/ProductDetail/CUI-Devices/CMI-9605IC-0580T)
 | S w I t c h
24 | BR1 | PEC11H-4020F-S0016 | D (https://www.bourns.com/docs/Product-Datasheets/PEC11H.pdf) | Bourns | Thr. Hole | Encoder Mechanical 16 PPR | 1 | 4.4 | 4.400 |  | 118-PEC11H-4020F-S0016-ND (https://www.digikey.com/en/products/detail/bourns-inc/PEC11H-4020F-S0016/12349534) | 652-PEC11H4020FS0016 (https://ru.mouser.com/ProductDetail/Bourns/PEC11H-4020F-S0016)
25 | BU1, BU2, BU3, BU4 | 1571563-8 | D | TE Conn. | SMD 6.0x6.00 | Switch tactile OFF-(ON) 6.0x6.0x5.0mm | 4 | 0.552 | 2.208 |  | 450-2056-1-ND (https://www.digikey.com/product-detail/en/te-connectivity-alcoswitch-switches/1571563-8/450-2056-1-ND/4569746) | 506-1571563-8 (https://ru.mouser.com/ProductDetail/TE-Connectivity-PB/1571563-8)
26 | SW1 | EG2208A | D (https://sten-eswitch-13110800-production.s3.amazonaws.com/system/asset/product_line/data_sheet/119/EG.pdf) | E-Switch | Thr. Hole, Right Ang. | Switch ON-ON 0.3A 50V | 1 | 1.12 | 1.120 |  | EG1942-ND (https://www.digikey.com/en/products/detail/e-switch/EG2208A/301964?s=N4IgTCBcDaIKIHExgAwA4CCIC6BfIA) | 612-EG2208A (https://ru.mouser.com/ProductDetail/E-Switch/EG2208A)
 | T r a n s I s t o r s
27 | Q1, Q3, Q5 | IRLML6244TRPBF | D (https://www.infineon.com/dgdl/irlml6244pbf.pdf?fileId=5546d462533600a4015356686fed261f) | Infineon | SOT23-3 | MOSFET N-channel, 20V, 6.3A, 21mOhm | 3 | 0.65 | 1.950 |  | IRLML6244TRPBFCT-ND (https://www.digikey.com/en/products/detail/infineon-technologies/IRLML6244TRPBF/2393871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) | 942-IRLML6244TRPBF (https://ru.mouser.com/ProductDetail/Infineon-IR/IRLML6244TRPBF)
28 | Q2, Q4 | DMC2400UV-7 | D (https://www.diodes.com/assets/Datasheets/DMC2400UV.pdf) | Diodes Inc. | SOT-563 | MOSFETs N and P-channel (Dual); 20V, 1A; ESD protected | 2 | 0.65 | 1.300 |  | DMC2400UV-7DICT-ND (https://www.digikey.com/product-detail/en/diodes-incorporated/DMC2400UV-7/DMC2400UV-7DICT-ND/2918407) | 21-DMC2400UV-7 (https://ru.mouser.com/ProductDetail/Diodes-Incorporated/DMC2400UV-7)
29 | Q6-Q13 | IXTH240N15X4 | D (https://www.littelfuse.com/~/media/electronics/datasheets/discrete_mosfets/littelfuse_discrete_mosfets_n-channel_ultra_junction_ixt_240n15x4_datasheet.pdf.pdf) | IXYS | TO247-3 | MOSFET N-chanel, 150V, 240A, 4.4mOhm | 8 | 19.15 | 153.200 |  | IXTH240N15X4-ND (https://www.digikey.com/en/products/detail/ixys/IXTH240N15X4/10222203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) | 747-IXTH240N15X4 (https://ru.mouser.com/ProductDetail/IXYS/IXTH240N15X4?qs=T3oQrply3y%252BbuTinOhn9MQ%3D%3D)
 | Alternative | IRFP3077PbF | D (https://www.infineon.com/dgdl/irfp3077pbf.pdf?fileId=5546d462533600a401535628cd701fee) | IXYS | TO247-3 | MOSFET N-chanel, 75V, 200A, 2.8mOhm | 8 | 8 |  |  | IRFP3077PbF (https://www.digikey.com/en/products/detail/infineon-technologies/IRFP3077PBF/1894148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) | 942-IRFP3077PBF (https://ru.mouser.com/ProductDetail/Infineon-IR/IRFP3077PBF)
 | C r y s t a l
30 | Y1 | ECS-80-20-5PX-TR | D (https://ecsxtal.com/store/pdf/csm-7x.pdf) | ECS Inc. | HC-49/US | Crystal 8MHz 20pF 30ppm | 1 | 0.44 | 0.440 |  | XC2076CT-ND (https://www.digikey.com/product-detail/en/ecs-inc/ECS-80-20-5PX-TR/XC2076CT-ND/5875560) | 520-80-20-5PX-T (https://ru.mouser.com/ProductDetail/ECS/ECS-80-20-5PX-TR?qs=wYonFgBYHKlzFXpOtPA%2FIw%3D%3D)
 | C a p a c i t o r
31 | C1, C14, C38, C83, C84, C88, C91, C128, C129, C131, C134 | C1210C106M6PACTU | D (https://content.kemet.com/datasheets/KEM_C1006_X5R_SMD.pdf) | KEMET | SMD1210 | Ceramic 10uF 20% X5R 35V | 11 | 2.66 | 29.260 |  | 399-5509-1-ND (https://www.digikey.com/en/products/detail/kemet/C1210C106M6PACTU/1950669) | 80-C1210C106M6P (https://ru.mouser.com/ProductDetail/KEMET/C1210C106M6PACTU)
32 | C2, C8, C82, C85, C127, C130 | GRT188R61H105KE13D | D (https://search.murata.co.jp/Ceramy/image/img/A01X/G101/ENG/GRT188R61H105KE13-01.pdf) | Murata | SMD0603 | Ceramic 1uF 10% X5R 50V | 6 | 0.42 | 2.520 |  | 490-12330-1-ND (https://www.digikey.com/en/products/detail/murata-electronics/GRT188R61H105KE13D/5416752) | 81-GRT188R61H105KE3D (https://ru.mouser.com/ProductDetail/Murata-Electronics/GRT188R61H105KE13D)
33 | C3, C9 | C0603C104K5RAC7082 | D (https://content.kemet.com/datasheets/KEM_C1002_X7R_SMD.pdf) | KEMET | SMD0603 | Ceramic 0.1uF 10% X7R 50V | 2 | 0.42 | 0.840 |  | 399-C0603C104K5RAC7082CT-ND (https://www.digikey.com/en/products/detail/kemet/C0603C104K5RAC7082/12701309) | 80-C0603C104K5R7082 (https://ru.mouser.com/ProductDetail/KEMET/C0603C104K5RAC7082)
34 | C4, C12, C17, C21, C28, C80, C81, C100, C103, C116, C119, C125, C126 | C1608X7R1E105K080AB | D (https://product.tdk.com/en/system/files) | TDK | SMD0603 | Ceramic 1uF 10% X7R 25V | 13 | 0.32 | 4.160 |  | 445-5956-1-ND (https://www.digikey.com/en/products/detail/tdk-corporation/C1608X7R1E105K080AB/2443434) | 810-C1608X7R1E105K (https://ru.mouser.com/ProductDetail/TDK/C1608X7R1E105K080AB)
35 | C5, C6 | RL81V101MDN1KX | D (http://nichicon-us.com/english/products/pdfs/e-rl8.pdf) | Nichicon | Radial, T/H 8.0x8.0 | Polymer Radial 100µF 20% 35V 25mOhm 2000h | 2 | 3.27 | 6.540 |  | 493-6630-1-ND (https://www.digikey.com/product-detail/en/nichicon/RL81V101MDN1KX/493-6630-1-ND/3466042) | 647-RL81V101MDN1KX (https://ru.mouser.com/ProductDetail/Nichicon/RL81V101MDN1KX)
 | Alternative | JRB1V221M03500800120000B | D (https://static.chipdip.ru/lib/762/DOC005762382.pdf) | JB | Radial, T/H 8.0x12.0 | Eletrolytic Radial 220µF 20% 35V 2000h | 2 | 0.1
36 | C7, C13, C15, C19, C20, C26, C30, C40, C43, C45, C46, C47, C48, C49, C94, C95, C110, C111, C124 | GRM1885C1H103JA01D | D (https://www.murata.com/-/media/webrenewal/support/library/catalog/products/capacitor/ceramiccapacitor/c02e.ashx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) | Murata | SMD0603 | Ceramic 0.01uF 5% NP0 50V | 19 | 0.31 | 5.890 |  | 490-9666-1-ND (https://www.digikey.com/en/products/detail/murata-electronics/GRM1885C1H103JA01D/4421555) | 81-GRM1885C1H103JA1D (https://ru.mouser.com/ProductDetail/Murata-Electronics/GRM1885C1H103JA01D)
37 | C10, C25, C34 | C1210C107M8PACTU | D (https://content.kemet.com/datasheets/KEM_C1006_X5R_SMD.pdf) | KEMET | SMD1210 | Ceramic 100uF 20% X5R 10V | 3 | 4.23 | 12.690 |  | 399-11631-1-ND (https://www.digikey.com/en/products/detail/kemet/C1210C107M8PACTU/4918884) | 80-C1210C107M8P (https://ru.mouser.com/ProductDetail/KEMET/C1210C107M8PACTU)
38 | C11 | RL81C331MDN1KX | D (https://www.nichicon.co.jp/english/products/pdfs/e-rl8.pdf) | Nichicon | Radial, T/H 9.0x8.0 | Polymer Radial 330µF 20% 16V 12mOhm 2000h | 1 | 1.51 | 1.510 |  | 493-6629-1-ND (https://www.digikey.com/en/products/detail/nichicon/RL81C331MDN1KX/3466040) | 647-RL81C331MDN1KX (https://ru.mouser.com/ProductDetail/Nichicon/RL81C331MDN1KX)
39 | C16, C18, C22, C23, C24, C27, C29, C31, C32, C33, C35, C36, C37, C39, C44, C86, C87, C92, C93, C101, C102, C105, C106, C108, C109, C117, C118, C121, C122, C135, C136 | C0603C104K3RAC7082 | D (https://content.kemet.com/datasheets/KEM_C1002_X7R_SMD.pdf) | KEMET | SMD0603 | Ceramic 0.1uF 10% X7R 25V | 31 | 0.32 | 9.920 |  | 399-C0603C104K3RAC7082CT-ND (https://www.digikey.com/en/products/detail/kemet/C0603C104K3RAC7082/12700954) | 80-C0603C104K3R7082 (https://ru.mouser.com/ProductDetail/KEMET/C0603C104K3RAC7082)
40 | C41, C42 | C0603C270J5GAC7411 | D (https://content.kemet.com/datasheets/KEM_C1003_C0G_SMD.pdf) | KEMET | SMD0603 | Ceramic 27pF 5% NP0 50V | 2 | 0.23 | 0.460 |  | 399-C0603C270J5GAC7411CT-ND (https://www.digikey.com/en/products/detail/kemet/C0603C270J5GAC7411/12701403) | 80-C0603C270J5GACLR (https://ru.mouser.com/ProductDetail/KEMET/C0603C270J5GAC7411)
41 | C50-C69 | EEU-FC2A681 | D (https://industrial.panasonic.com/cdbs/www-data/pdf/RDF0000/ABA0000C1209.pdf) | Panasonic | Radial, T/H 40.0x18.0 | Capacitor Aluminum Electrolytic Radial 680µF 100V 36mOhm 5000h | 20 | 4.81 | 96.200 |  | P10875-ND (https://www.digikey.com/en/products/detail/panasonic-electronic-components/EEU-FC2A681/285738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) | 667-EEU-FC2A681 (https://ru.mouser.com/ProductDetail/Panasonic/EEU-FC2A681)
42 | C70-C79 | C2220C105KARACTU | D (https://content.kemet.com/datasheets/KEM_C1011_X7R_TIP_RING_SMD.pdf) | KEMET | SMD2220 | Ceramic 1uF 10% X7R 250V | 10 | 5 | 50.000 |  | 399-4690-1-ND (https://www.digikey.com/en/products/detail/kemet/C2220C105KARACTU/992183) | 80-C2220C105KAR (https://ru.mouser.com/ProductDetail/KEMET/C2220C105KARACTU)
43 | C89, C90, C104, C107, C120, C123, C132, C133 | C1608X5R1E225K080AB | D (https://product.tdk.com/en/system/files) | TDK | SMD0603 | Ceramic 2.2uF 10% X5R 25V | 8 | 0.37 | 2.960 |  | 445-5964-1-ND (https://www.digikey.com/en/products/detail/tdk-corporation/C1608X5R1E225K080AB/2443442) | 810-C1608X5R1E225K (https://ru.mouser.com/ProductDetail/TDK/C1608X5R1E225K080AB)
44 | C96, C97, C112, C113 | CGA8M1C0G3F221K200KA | D (https://product.tdk.com/en/system/files) | TDK | SMD1812 | Ceramic 220pF 10% NP0 3kV | 4 | 1.44 | 5.760 |  | 445-13094-1-ND (https://www.digikey.com/en/products/detail/tdk-corporation/CGA8M1C0G3F221K200KA/3950330) | 810-CGA8M1C0G3F221KA (https://ru.mouser.com/ProductDetail/TDK/CGA8M1C0G3F221K200KA)
45 | C98, C99, C114, C115 | GRM1885C1H100JA01D | D (https://www.murata.com/-/media/webrenewal/support/library/catalog/products/capacitor/ceramiccapacitor/c02e.ashx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) | Murata | SMD0603 | Ceramic 10pF 5% NP0 50V | 4 | 0.2 | 0.800 |  | 490-1403-1-ND (https://www.digikey.com/en/products/detail/murata-electronics/GRM1885C1H100JA01D/586930) | 81-GRM39C100D50 (https://ru.mouser.com/ProductDetail/Murata-Electronics/GRM1885C1H100JA01D)
 | R e s i s t o r
46 | R1,R4, R7, R11, R13, R24, R28, R41, R42, R44, R46, R54, R57, R58, R61, R76, R77, R78, R79, R80, R81, R83, R85, R86, R99, R102, R113, R116, R119, R120 | ERJ-3EKF1002V | D (https://industrial.panasonic.com/cdbs/www-data/pdf/RDA0000/AOA0000C304.pdf) | Panasonic | SMD0603 | 10kOhm 1% 100ppm 0.1W | 30 | 0.1 | 3.000 |  | P10.0KHCT-ND (https://www.digikey.com/product-detail/en/panasonic-electronic-components/ERJ-3EKF1002V/P10-0KHCT-ND/198102) | 667-ERJ-3EKF1002V (https://ru.mouser.com/ProductDetail/Panasonic/ERJ-3EKF1002V)
47 | R2, R3, R6, R8, R12, R14, R16, R17, R21, R22, R23, R27, R32, R35, R38, R39, R43, R55, R68, R74, R75, R89, R90, R91, R92, R103, R104, R105, R106 | ERJ-3EKF1001V | D (https://industrial.panasonic.com/cdbs/www-data/pdf/RDA0000/AOA0000C304.pdf) | Panasonic | SMD0603 | 1kOhm 1% 100ppm 0.1W | 29 | 0.1 | 2.900 |  | P1.00KHCT-ND (https://www.digikey.com/product-detail/en/panasonic-electronic-components/ERJ-3EKF1001V/P1-00KHCT-ND/198071) | 667-ERJ-3EKF1001V (https://ru.mouser.com/ProductDetail/Panasonic/ERJ-3EKF1001V)
48 | R5, R15, R26, R33 | non |  |  | SMD0603 |  | 4 |  | 0.000
49 | R9, R10, R18, R20, R29, R30, R31 | ERJ-3EKF10R0V | D (https://industrial.panasonic.com/cdbs/www-data/pdf/RDA0000/AOA0000C304.pdf) | Panasonic | SMD0603 | 10Ohm 1% 100ppm 0.1W | 7 | 0.1 | 0.700 |  | P10.0HCT-ND (https://www.digikey.com/en/products/detail/panasonic-electronic-components/ERJ-3EKF10R0V/196065) | 667-ERJ-3EKF10R0V (https://ru.mouser.com/ProductDetail/Panasonic/ERJ-3EKF10R0V)
50 | R19, R37, R51, R52, R56, R59, R65, R66 | ERJ-3EKF2000V | D (https://industrial.panasonic.com/cdbs/www-data/pdf/RDA0000/AOA0000C304.pdf) | Panasonic | SMD0603 | 200Ohm 1% 100ppm 0.1W | 8 | 0.1 | 0.800 |  | P200HCT-ND (https://www.digikey.com/en/products/detail/panasonic-electronic-components/ERJ-3EKF2000V/196205) | 667-ERJ-3EKF2000V (https://ru.mouser.com/ProductDetail/Panasonic/ERJ-3EKF2000V)
51 | R25, R36, R40, R45, R47, R49, R50, R53, R63, R64, R67, R73, R82, R84, R93, R94, R107, R108, R117 | ERJ-3EKF1000V | D (https://industrial.panasonic.com/cdbs/www-data/pdf/RDA0000/AOA0000C304.pdf) | Panasonic | SMD0603 | 100Ohm 1% 100ppm 0.1W | 19 | 0.1 | 1.900 |  | P100HCT-ND (https://www.digikey.com/product-detail/en/panasonic-electronic-components/ERJ-3EKF1000V/P100HCT-ND/198109) | 667-ERJ-3EKF1000V (https://ru.mouser.com/ProductDetail/Panasonic/ERJ-3EKF1000V)
52 | R34 | ERJ-U03J105V | D (https://industrial.panasonic.com/cdbs/www-data/pdf/RDP0000/AOA0000C334.pdf) | Panasonic | SMD0603 | 1MOhm 5% 200ppm 0.1W | 1 | 0.1 | 0.100 |  | 10-ERJ-U03J105VCT-ND (https://www.digikey.com/en/products/detail/panasonic-electronic-components/ERJ-U03J105V/11636001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) | 667-ERJ-U03J105V (https://ru.mouser.com/ProductDetail/Panasonic/ERJ-U03J105V)
53 | R48 | ERJ-3EKF1801V | D (https://industrial.panasonic.com/cdbs/www-data/pdf/RDA0000/AOA0000C304.pdf) | Panasonic | SMD0603 | 1.8kOhm 1% 100ppm 0.1W | 1 | 0.1 | 0.100 |  | P1.80KHCT-ND (https://www.digikey.com/en/products/detail/panasonic-electronic-components/ERJ-3EKF1801V/1746325) | 667-ERJ-3EKF1801V (https://ru.mouser.com/ProductDetail/Panasonic/ERJ-3EKF1801V)
54 | R60 | ERJ-3EKF2202V | D (https://industrial.panasonic.com/cdbs/www-data/pdf/RDA0000/AOA0000C304.pdf) | Panasonic | SMD0603 | 22kOhm 1% 100ppm 0.1W | 1 | 0.1 | 0.100 |  | P22.0KHCT-ND (https://www.digikey.com/en/products/detail/panasonic-electronic-components/ERJ-3EKF2202V/1746336) | 667-ERJ-3EKF2202V (https://ru.mouser.com/ProductDetail/Panasonic/ERJ-3EKF2202V)
55 | R62 | ERJ-3EKF4302V | D (https://industrial.panasonic.com/cdbs/www-data/pdf/RDA0000/AOA0000C304.pdf) | Panasonic | SMD0603 | 43kOhm 1% 100ppm 0.1W | 1 | 0.1 | 0.100 |  | P43.0KHCT-ND (https://www.digikey.com/en/products/detail/panasonic-electronic-components/ERJ-3EKF4302V/1746411) | 667-ERJ-3EKF4302V (https://ru.mouser.com/ProductDetail/Panasonic/ERJ-3EKF4302V)
56 | R69, R70, R71, R72 | ERJ-3EKF3301V | D (https://industrial.panasonic.com/cdbs/www-data/pdf/RDA0000/AOA0000C304.pdf) | Panasonic | SMD0603 | 3.3kOhm 1% 100ppm 0.1W | 4 | 0.1 | 0.400 |  | P3.30KHCT-ND (https://www.digikey.com/en/products/detail/panasonic-electronic-components/ERJ-3EKF3301V/1746376) | 667-ERJ-3EKF3301V (https://ru.mouser.com/ProductDetail/Panasonic/ERJ-3EKF3301V)
57 | R87, R88, R122, R123 | ERJ-3EKF5101V | D (https://industrial.panasonic.com/cdbs/www-data/pdf/RDA0000/AOA0000C304.pdf) | Panasonic | SMD0603 | 5.1kOhm 1% 100ppm 0.1W | 4 | 0.1 | 0.400 |  | P5.10KHCT-ND (https://www.digikey.com/en/products/detail/panasonic-electronic-components/ERJ-3EKF5101V/1746427) | 667-ERJ-3EKF5101V (https://ru.mouser.com/ProductDetail/Panasonic/ERJ-3EKF5101V)
58 | R95, R95A, R96, R96A, R97, R97A, R98, R98A, R109, R109A, R110, R110A, R111, R111A, R112, R112A | ERJ-6RQF1R0V | D (https://industrial.panasonic.com/cdbs/www-data/pdf/RDN0000/AOA0000C313.pdf) | Panasonic | SMD0603 | 1Ohm 1% 100ppm 0.1W | 16 | 0.32 | 5.120 |  | P1.0DCT-ND (https://www.digikey.com/en/products/detail/panasonic-electronic-components/ERJ-6RQF1R0V/250172) | 667-ERJ-6RQF1R0V (https://ru.mouser.com/ProductDetail/Panasonic/ERJ-6RQF1R0V)
59 | R100, R100A, R100B, R100C, R101, R101A, R101B, R101C, R114, R114A, R114B, R114C, R115, R115A, R115B, R115C | ERJ-1TYJ510U | D (https://media.digikey.com/pdf/Data%20Sheets/Panasonic%20Resistors%20Thermistors%20PDFs/ERJ-xG,14,12(Z),1T_Rev_Apr_2015.pdf) | Panasonic | SMD2512 | 51Ohm 5% 200ppm 1W | 16 | 0.32 | 5.120 |  | PT51XCT-ND (https://www.digikey.com/en/products/detail/panasonic-electronic-components/ERJ-1TYJ510U/365222) | 667-ERJ-1TYJ510U (https://ru.mouser.com/ProductDetail/Panasonic/ERJ-1TYJ510U)
60 | R118 | CSSH2728FT5L00 | D (https://www.seielect.com/catalog/sei-css_cssh.pdf) | Stackpole | SMD2728 | 5mOhms 1% 25ppm 4W | 1 | 1 | 1.000 |  | CSSH2728FT5L00CT-ND (https://www.digikey.com/en/products/detail/stackpole-electronics-inc/CSSH2728FT5L00/1923229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) | -
61 | R121 | ERJ-6GEY0R00V | D (https://industrial.panasonic.com/cdbs/www-data/pdf/RDA0000/AOA0000C301.pdf) | Panasonic | SMD0805 | 0Ohm | 1 | 0.1 | 0.100 |  | P0.0ACT-ND (https://www.digikey.com/en/products/detail/panasonic-electronic-components/ERJ-6GEY0R00V/78163) | 667-ERJ-6GEY0R00V (https://ru.mouser.com/ProductDetail/Panasonic/ERJ-6GEY0R00V)
62 | RT1, RT2, RT3, RT4 | B57861S0103J040 | D (https://www.tdk-electronics.tdk.com/inf/50/db/ntc/NTC_Mini_sensors_S861.pdf) | TDK-EPCOS | T/H | NTC resistor 10kOhm 5% 3988K | 4 | 1.89 | 7.560 |  | 495-75200-ND (https://www.digikey.com/en/products/detail/epcos-tdk-electronics/B57861S0103J040/3500452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) | 871-B57861S103J40 (https://ru.mouser.com/ProductDetail/EPCOS-TDK/B57861S0103J040)
 | C o n n e c t o r
63 | X1 | 0039281043 | D (https://www.molex.com/pdm_docs/sd/039281043_sd.pdf) | Molex | T/H | Connector Header 4 pin, 4.2mm | 1 | 1.92 | 1.920 |  | WM3801-ND (https://www.digikey.com/en/products/detail/molex/0039281043/61400) | 538-39-28-1043 (https://ru.mouser.com/ProductDetail/Molex/39-28-1043?qs=LQQHZ4xw2XCMHoV0KRLGhg%3D%3D)
64 | X2, X4 | WF-2R | D (https://static.chipdip.ru/lib/143/DOC006143808.pdf) | Connfly | T/H | Connector 2 pin, Right angle, 2.54mm | 2 | 0.07 | 0.140 |  | - | - | ChipDip (https://www.chipdip.ru/product/wf-2r)
65 | X3, X5 | SMA-J-P-H-RA-TH1 | D (http://suddendocs.samtec.com/catalog_english/sma.pdf) | Samtec | T/H | SMA Jack, Socket, Right Angle 50Ohm | 2 | 7 | 14.000 |  | SAM8856-ND (https://www.digikey.com/en/products/detail/samtec-inc/SMA-J-P-H-RA-TH1/2664715) | 200-SMAJPHRATH1 (https://ru.mouser.com/ProductDetail/Samtec/SMA-J-P-H-RA-TH1)
66 | X6 | 1074 | D (http://www.keystoneelectronics.net/ENG._DEPT/WEB_ORACLE/PDF/PDF%20CAT%20NO%20DRAWINGS/1000-1999/1074.PDF) | Keystone | T/H | Battery holder for CR2032 | 1 | 1.09 | 1.090 |  | 36-1074-ND (https://www.digikey.com/en/products/detail/keystone-electronics/1074/9921784) | 534-1074 (https://ru.mouser.com/ProductDetail/Keystone-Electronics/1074?qs=u16ybLDytRZ%2FZj7HSRmD5g%3D%3D)
67 | X7 | PLS2-5 | D (https://static.chipdip.ru/lib/245/DOC000245332.pdf) | Connfly | T/H | Connector Header 5 pin, 2mm | 1 | 0.05 | 0.050 | SWD connector | - | - | ChipDip (https://www.chipdip.ru/product/ds1025-01-1-5-p8bv1-pls2-5-pls2-05)
68 | X8 | SS-52400-003 | D (https://belfuse.com/resources/drawings/stewartconnector/dr-stw-ss-52400-003.pdf) | Stewart | SMD+T/H | USB Type-C, Right Angle Receptacle 24 Position | 1 | 3.5 | 3.500 |  | 380-SS-52400-003CT-ND (https://www.digikey.com/en/products/detail/stewart-connector/SS-52400-003/11205655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) | 530-SS-52400-003 (https://ru.mouser.com/ProductDetail/Stewart-Connector-Bel/SS-52400-003)
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

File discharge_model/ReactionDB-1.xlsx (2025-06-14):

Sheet: Reactions
ε | 2.359 |  | Te |  | 18250.74465 | K |  | Tg | 303 | K |  |  | NM | 2.7e+25 |  | m-3 |  | Teff | 303 |  | O(1D) | NO3 |  |  | k | 8.617e-05 | eV/K
Code | Reaction |  |  |  |  |  |  |  |  |  |  |  |  | Rate constant |  |  | Comments | Ref. |  |  | Reactant | Product
(R23) | e | + | N2O5 |  |  | → | e ION | → | NO2+ | + | NO3 | + | 2e | 1.466107558e-17 | 1.466107558e-17 | 2.43 × 10-17ε × 2.77 exp(-5.62/ε) |  | Sakyama |  |  | FALSE | TRUE |  | e + N2O5->NO2+ + NO3 + 2e | 1.466107558e-17
(R34) | e | + | O4+ |  |  | → | e NEUT | → | 2O2 |  |  |  |  | 1.794933522e-13 | 1.794933522e-13 | 1.4 × 10-12(300/Te)0.5 |  | Sakyama |  | [11] | FALSE | FALSE | Verified | e + O4+->2O2 + | 1.794933522e-13
(R325) | N+ | + | OH- |  |  | → | I-I NEUT | → | N | + | OH |  |  | 1.99007438e-13 | 1.99007438e-13 | 2 × 10-13 (300/Tg)0.5 |  | Sakyama |  | c | FALSE | FALSE |  | N+ + OH-->N + OH | 1.99007438e-13
(R26) | e | + | N2+ |  |  | → | e NEUT | → | N(2D) | + | N |  |  | 3.626188404e-14 | 1.560252355e-15 | 1.8 × 10-13(300/Te)0.39 |  | Sakyama |  | [11] | FALSE | FALSE | Verified | e + N2+->N(2D) + N | 3.626188404e-14
(R29) | e | + | N4+ |  |  | → | e NEUT | → | 2N2 |  |  |  |  | 2.606894099e-14 | 2.606894099e-14 | 2.3 × 10-13(300/Te)0.53 |  | Sakyama |  | [11] | FALSE | FALSE | Verified | e + N4+->2N2 + | 2.606894099e-14
(R28) | e | + | N3+ |  |  | → | e NEUT | → | N2 | + | N |  |  | 2.564190746e-14 | 2.564190746e-14 | 2 × 10-13(300/Te)0.5 |  | Sakyama |  | [11] | FALSE | FALSE | Verified | e + N3+->N2 + N | 2.564190746e-14
(R35) | e | + | N2O+ |  |  | → | e NEUT | → | N2 | + | O |  |  | 2.564190746e-14 | 2.564190746e-14 | 2 × 10-13(300/Te)0.5 |  | Sakyama |  | [11] | FALSE | FALSE | Verified | e + N2O+->N2 + O | 2.564190746e-14
(R39) | e | + | NO2+ |  |  | → | e NEUT | → | NO | + | O |  |  | 2.564190746e-14 | 2.564190746e-14 | 2.0 × 10-13 (300/Te)0.5 |  | Sakyama |  | [11] | FALSE | FALSE | Verified | e + NO2+->NO + O | 2.564190746e-14
(R286) | O+ | + | OH- |  |  | → | I-I NEUT | → | O | + | OH |  |  | 1.99007438e-13 | 1.99007438e-13 | 2 × 10-13 (300/Tg)0.5 |  | Sakyama |  | c | FALSE | FALSE |  | O+ + OH-->O + OH | 1.99007438e-13
(R32) | e | + | O2+ |  |  | → | e NEUT | → | O | + | O(1D) |  |  | 1.293811944e-14 | 1.293811944e-14 | 2.295 × 10-13(300/Te)0.7 |  | Sakyama |  | [11] | FALSE | FALSE | Verified | e + O2+->O + O(1D) | 1.293811944e-14
(R37) | e | + | NO+ |  |  | → | e NEUT | → | N(2D) | + | O |  |  | 1.022830909e-14 | 1.022830909e-14 | 3.36 × 10-13 (300/Te)0.85 |  | Sakyama |  | [11] | FALSE | FALSE | Verified | e + NO+->N(2D) + O | 1.022830909e-14
(R44) | e | + | H2O+ |  |  | → | e NEUT | → | O | + | H2 |  |  | 1.014098809e-14 | 1.014098809e-14 | 1.37 × 10-12/Te0.5 |  | Sakyama |  | [16] | FALSE | FALSE |  | e + H2O+->O + H2 | 1.014098809e-14
(R45) | e | + | H2O+ |  |  | → | e NEUT | → | O | + | 2H |  |  | 1.014098809e-14 | 1.014098809e-14 | 1.37 × 10-12/Te0.5 |  | Sakyama |  | [16] | FALSE | FALSE |  | e + H2O+->O + 2H | 1.014098809e-14
(R40) | e | + | H2+ |  |  | → | e NEUT | → | 2H |  |  |  |  | 2.736291057e-15 | 2.736291057e-15 | 1.86 × 10-13/Te0.43 |  | Sakyama |  | [16] | FALSE | FALSE |  | e + H2+->2H + | 2.736291057e-15
(R36) | e | + | NO+ |  |  | → | e NEUT | → | N | + | O |  |  | 2.557077271e-15 | 2.557077271e-15 | 0.84 × 10-13 (300/Te)0.85 |  | Sakyama |  | [11] | FALSE | FALSE | Verified | e + NO+->N + O | 2.557077271e-15
(R31) | e | + | O2+ |  |  | → | e NEUT | → | 2O |  |  |  |  | 2.283197548e-15 | 2.283197548e-15 | 0.405 × 10-13(300/Te)0.7 |  | Sakyama |  | [11] | FALSE | FALSE | Verified | e + O2+->2O + | 2.283197548e-15
(R42) | e | + | H3+ |  |  | → | e NEUT | → | 3H |  |  |  |  | 2.046234924e-15 | 8.384220281e-16 | 0.71 × 1.55 × 10-13 (300/Te)0.97 |  | Sakyama |  | [11] | FALSE | FALSE | Verified | e + H3+->3H + | 2.046234924e-15
(R25) | e | + | N2+ |  |  | → | e NEUT | → | 2N |  |  |  |  | 1.726679273e-15 | 1.726679273e-15 | 1.66 × 10-12/Te0.7 |  | Sakyama |  | [9] | FALSE | FALSE |  | e + N2+->2N + | 1.726679273e-15
(R41) | e | + | H3+ |  |  | → | e NEUT | → | H | + | H2 |  |  | 8.357860958e-16 | 3.849134166e-13 | 0.29 × 1.55 × 10-13 (300/Te)0.97 |  | Sakyama |  | [11] | FALSE | FALSE | Verified | e + H3+->H + H2 | 8.357860958e-16
(R316) | N+ | + | N2O- |  |  | → | I-I NEUT | → | N2O | + | N |  |  | 1.99007438e-13 | 1.99007438e-13 | 2 × 10-13 (300/Tg)0.5 |  | Sakyama |  | [9] | FALSE | FALSE |  | N+ + N2O-->N2O + N | 1.99007438e-13
(R30) | e | + | O+ | + | M | → | e NEUT (TBA) | → | O | + | M |  |  | 3.416626263e-16 | 3.416626263e-16 | 3.12 × 10-35/Te1.5 |  | Sakyama |  | [9] | FALSE | FALSE |  | e + O+ + M->O + M | 3.416626263e-16
(R33) | e | + | O2+ | + | M | → | e NEUT (TBA) | → | O2 | + | M |  |  | 3.416626263e-16 | 3.416626263e-16 | 3.12 × 10-35/Te1.5 |  | Sakyama |  | [9] | FALSE | FALSE |  | e + O2+ + M->O2 + M | 3.416626263e-16
(R38) | e | + | NO+ | + | M | → | e NEUT (TBA) | → | NO | + | M |  |  | 3.416626263e-16 | 3.416626263e-16 | 3.12 × 10-35/Te1.5 |  | Sakyama |  | [9] | FALSE | FALSE |  | e + NO+ + M->NO + M | 3.416626263e-16
(R317) | N+ | + | NO- |  |  | → | I-I NEUT | → | NO | + | N |  |  | 1.99007438e-13 | 1.99007438e-13 | 2 × 10-13 (300/Tg)0.5 |  | Sakyama |  | [9] | FALSE | FALSE |  | N+ + NO-->NO + N | 1.99007438e-13
(R48) | 2e | + | N2+ |  |  | → | e NEUT | → | N2 | + | e |  |  | 9.788793756e-40 | 9.788793756e-40 | 1 × 10-31 (Tg/Te)4.5 |  | Sakyama |  | [9] | FALSE | FALSE |  | 2e + N2+->N2 + e | 9.788793756e-40
(R49) | 2e | + | O+ |  |  | → | e NEUT | → | O | + | e |  |  | 9.788793756e-40 | 9.788793756e-40 | 1 × 10-31 (Tg/Te)4.5 |  | Sakyama |  | [9] | FALSE | FALSE |  | 2e + O+->O + e | 9.788793756e-40
(R50) | 2e | + | O2+ |  |  | → | e NEUT | → | O2 | + | e |  |  | 9.788793756e-40 | 9.788793756e-40 | 1 × 10-31 (Tg/Te)4.5 |  | Sakyama |  | [9] | FALSE | FALSE |  | 2e + O2+->O2 + e | 9.788793756e-40
(R51) | 2e | + | NO+ |  |  | → | e NEUT | → | NO | + | e |  |  | 9.788793756e-40 | 9.788793756e-40 | 1 × 10-31 (Tg/Te)4.5 |  | Sakyama |  | [9] | FALSE | FALSE |  | 2e + NO+->NO + e | 9.788793756e-40
(R52) | 2e | + | H+ |  |  | → | e NEUT | → | H | + | e |  |  | 9.788793756e-40 | 9.788793756e-40 | 1 × 10-31 (Tg/Te)4.5 |  | Sakyama |  | c | FALSE | FALSE |  | 2e + H+->H + e | 9.788793756e-40
(R53) | 2e | + | H2+ |  |  | → | e NEUT | → | H2 | + | e |  |  | 9.788793756e-40 | 9.788793756e-40 | 1 × 10-31 (Tg/Te)4.5 |  | Sakyama |  | c | FALSE | FALSE |  | 2e + H2+->H2 + e | 9.788793756e-40
(R304) | O2+ | + | OH- |  |  | → | I-I NEUT | → | OH | + | O2 |  |  | 1.99007438e-13 | 1.99007438e-13 | 2 × 10-13 (300/Tg)0.5 |  | Sakyama |  | c | FALSE | FALSE |  | O2+ + OH-->OH + O2 | 1.99007438e-13
(R55) | 2e | + | H2O+ |  |  | → | e NEUT | → | H2O | + | e |  |  | 9.788793756e-40 | 9.788793756e-40 | 1 × 10-31 (Tg/Te)4.5 |  | Sakyama |  | c | FALSE | FALSE |  | 2e + H2O+->H2O + e | 9.788793756e-40
 | e | + | O3 |  |  | → | e DEA | → | O2- | + | O |  |  | 1e-15 |  | 1.0 × 10-15 |  |  |  | [11] | FALSE | FALSE | Verified | e + O3->O2- + O | 1e-15
 | e | + | O3 |  |  | → | e DEA | → | O2 | + | O- |  |  | 1e-17 |  | 1.0 × 10-17 |  |  |  | [11] | FALSE | FALSE | Verified | e + O3->O2 + O- | 1e-17
 | e | + | O2 | + | H2O | → | e DEA (TBA) | → | O2- | + | H2O |  |  | 3.78e-16 |  | 1.4 × 10-41 |  |  |  | [11] | FALSE | FALSE | Verified | e + O2 + H2O->O2- + H2O | 3.78e-16
(R64) | e | + | O3 | + | O2 | → | e DEA (TBA) | → | O3- | + | O2 |  |  | 2.7e-18 | 2.7e-18 | 1 × 10-43 |  | Sakyama |  | [11] | FALSE | FALSE | Verified | e + O3 + O2->O3- + O2 | 2.7e-18
(R65) | e | + | N2O |  |  | → | e DEA | → | O- | + | N2 |  |  | 2e-16 | 2e-16 | 2 × 10-16 |  | Sakyama |  | [18] | FALSE | FALSE |  | e + N2O->O- + N2 | 2e-16
(R66) | e | + | NO | + | NO | → | e DEA (TBA) | → | NO- | + | NO |  |  | 2.16e-17 | 2.16e-17 | 8 × 10-43 |  | Sakyama |  | [11] | FALSE | FALSE | Verified | e + NO + NO->NO- + NO | 2.16e-17
(R67) | e | + | NO2 |  |  | → | e DEA | → | O- | + | NO |  |  | 1e-17 | 1e-17 | 1 × 10-17 |  | Sakyama |  | [11] | FALSE | FALSE | Verified | e + NO2->O- + NO | 1e-17
(R68) | e | + | NO2 | + | M | → | e DEA (TBA) | → | NO2- | + | M |  |  | 4.05e-17 | 4.05e-17 | 1.5 × 10-42 |  | Sakyama |  | [8] | FALSE | FALSE | Verified | e + NO2 + M->NO2- + M | 4.05e-17
(R69) | e | + | NO3 | + | M | → | e DEA (TBA) | → | NO3- | + | M |  |  | 2.7e-17 | 2.7e-17 | 1 × 10-42 |  | Sakyama |  | [8] | FALSE | FALSE | Verified | e + NO3 + M->NO3- + M | 2.7e-17
(R470) | OH+ | + | O- |  |  | → | I-I NEUT | → | O | + | OH |  |  | 1.99007438e-13 | 1.99007438e-13 | 2 × 10-13 (300/Tg)0.5 |  | Sakyama |  | c | FALSE | FALSE |  | OH+ + O-->O + OH | 1.99007438e-13
A(6) | O2(4.5) | + | M |  |  | → | N-N Chem | → | O2 | + | M |  |  | 2.3e-20 | 2.3e-20 | 2.3 × 10-20 |  | Akishev |  |  | FALSE | FALSE |  | O2(4.5) + M->O2 + M | 2.3e-20
A(6) | O2(4.5) | + | M |  |  | → | N-N Chem | → | O2(a1) | + | M |  |  | 1.86e-19 | 1.86e-19 | 1.9 × 10-19 |  | Akishev |  |  | FALSE | FALSE |  | O2(4.5) + M->O2(a1) + M | 1.86e-19
A(6) | O2(4.5) | + | M |  |  | → | N-N Chem | → | O2(b1) | + | M |  |  | 8.1e-20 | 8.1e-20 | 8.1 × 10-20 |  | Akishev |  |  | FALSE | FALSE |  | O2(4.5) + M->O2(b1) + M | 8.1e-20
(R320) | N+ | + | O- |  |  | → | I-I NEUT | → | O | + | N |  |  | 1.99007438e-13 | 1.99007438e-13 | 2 × 10-13 (300/Tg)0.5 |  | Sakyama |  | [8] | FALSE | FALSE |  | N+ + O-->O + N | 1.99007438e-13
(R277) | O+ | + | O- |  |  | → | I-I NEUT | → | 2O |  |  |  |  | 1.99007438e-13 | 1.99007438e-13 | 2 × 10-13 (300/Teff)0.5 |  | Sakyama |  | [11] | FALSE | FALSE | Verified | O+ + O-->2O + | 1.99007438e-13
(R288) | O2+ | + | O- |  |  | → | I-I NEUT | → | O | + | O2 |  |  | 1.99007438e-13 | 1.99007438e-13 | 2 × 10-13 (300/Teff)0.5 |  | Sakyama |  | [11] | FALSE | FALSE | Verified | O2+ + O-->O + O2 | 1.99007438e-13
(R335) | N2+ | + | O- |  |  | → | I-I NEUT | → | O | + | N2 |  |  | 1.99007438e-13 | 1.99007438e-13 | 2 × 10-13 (300/Tg)0.5 |  | Sakyama |  | [9] | FALSE | FALSE |  | N2+ + O-->O + N2 | 1.99007438e-13
(R255) | H3+ | + | O |  |  | → | I-N REC | → | OH+ | + | H2 |  |  | 8e-16 | 8e-16 | 8 × 10-16 |  | Sakyama |  | [22] | FALSE | FALSE |  | H3+ + O->OH+ + H2 | 8e-16
(R353) | N2O+ | + | O- |  |  | → | I-I NEUT | → | O | + | N2O |  |  | 1.99007438e-13 | 1.99007438e-13 | 2 × 10-13 (300/Tg)0.5 |  | Sakyama |  | [9] | FALSE | FALSE |  | N2O+ + O-->O + N2O | 1.99007438e-13
(R393) | NO+ | + | O- |  |  | → | I-I NEUT | → | O | + | NO |  |  | 1.99007438e-13 | 1.99007438e-13 | 2 × 10-13 (300/Tg)0.5 |  | Sakyama |  | [8] | FALSE | FALSE |  | NO+ + O-->O + NO | 1.99007438e-13
(R411) | NO2+ | + | O- |  |  | → | I-I NEUT | → | O | + | NO2 |  |  | 1.99007438e-13 | 1.99007438e-13 | 2 × 10-13 (300/Tg)0.5 |  | Sakyama |  | [8] | FALSE | FALSE |  | NO2+ + O-->O + NO2 | 1.99007438e-13
(R426) | H+ | + | O- |  |  | → | I-I NEUT | → | O | + | H |  |  | 1.99007438e-13 | 1.99007438e-13 | 2 × 10-13 (300/Tg)0.5 |  | Sakyama |  | c | FALSE | FALSE |  | H+ + O-->O + H | 1.99007438e-13
(R441) | H2+ | + | O- |  |  | → | I-I NEUT | → | O | + | H2 |  |  | 1.99007438e-13 | 1.99007438e-13 | 2 × 10-13 (300/Tg)0.5 |  | Sakyama |  | c | FALSE | FALSE |  | H2+ + O-->O + H2 | 1.99007438e-13
(R84) | O2- | + | N |  |  | → | I-N DA | → | NO2 | + | e |  |  | 5e-16 | 5e-16 | 5 × 10-16 |  | Sakyama |  | [11] | FALSE | FALSE | Verified | O2- + N->NO2 + e | 5e-16
(R85) | O2- | + | N2 |  |  | → | I-N DA | → | N2 | + | O2 | + | e | 1.344843753e-25 | 1.344843753e-25 | 1.9 × 10-18 (Teff/300)0.5 exp(-4990/Teff) |  | Sakyama |  | [11] | FALSE | FALSE | Verified | O2- + N2->N2 + O2 + e | 1.344843753e-25
(R86) | O2- | + | N2(A3) |  |  | → | I-N DA | → | N2 | + | O2 | + | e | 2.1e-15 | 2.1e-15 | 2.1 × 10-15 |  | Sakyama |  | [11] | FALSE | FALSE | Verified | O2- + N2(A3)->N2 + O2 + e | 2.1e-15
(R87) | O2- | + | N2(esum) |  |  | → | I-N DA | → | N2 | + | O2 | + | e | 2.5e-15 | 2.5e-15 | 2.5 × 10-15 |  | Sakyama |  | [11] | FALSE | FALSE | Verified | O2- + N2(esum)->N2 + O2 + e | 2.5e-15
(R215) | O4- | + | O |  |  | → | I-N REC | → | O3- | + | O2 |  |  | 4e-16 | 4e-16 | 4 × 10-16 |  | Sakyama |  | [11] | FALSE | FALSE | Verified | O4- + O->O3- + O2 | 4e-16
(R89) | O2- | + | O2 |  |  | → | I-N DA | → | 2O2 | + | e |  |  | 2.638110122e-24 | 2.638110122e-24 | 2.7 × 10-16 (Teff/300)0.5 exp(-5590/Teff) |  | Sakyama |  | [11] | FALSE | FALSE | Verified | O2- + O2->2O2 + e | 2.638110122e-24
(R91) | O2- | + | O2(a1) |  |  | → | I-N DA | → | 2O2 | + | e |  |  | 2e-16 | 2e-16 | 2 × 10-16 |  | Sakyama |  | [11] | FALSE | FALSE | Verified | O2- + O2(a1)->2O2 + e | 2e-16
(R92) | O2- | + | H |  |  | → | I-N DA | → | HO2 | + | e |  |  | 1.4e-15 | 1.4e-15 | 1.4 × 10-15 |  | Sakyama |  | [19] | FALSE | FALSE |  | O2- + H->HO2 + e | 1.4e-15
(R242) | H+ | + | O |  |  | → | I-N REC | → | O+ | + | H |  |  | 3.8e-16 | 3.8e-16 | 3.8 × 10-16 |  | Sakyama |  | [11] | FALSE | FALSE | Verified | H+ + O->O+ + H | 3.8e-16
(R94) | O3- | + | O2 |  |  | → | I-N DA | → | O3 | + | O2 | + | e | 2.3e-17 | 2.3e-17 | 2.3 × 10-17 |  | Sakyama |  | [18] | FALSE | FALSE |  | O3- + O2->O3 + O2 + e | 2.3e-17
 | O3- | + | N2 |  |  | → | I-N DA | → | N2O | + | O2 | + | e | 1e-21 | 1e-21 |  |  |  |  | [11] | FALSE | FALSE | Verified | O3- + N2->N2O + O2 + e | 1e-21
 | O3- | + | N2 | + | N2 | → | I-N DA (TBA) | → | N2O | + | 2M | + | e | 1.5e-45 | 1.5e-45 |  |  |  |  |  | FALSE | FALSE |  | O3- + N2 + N2->N2O + 2M + e | 1.5e-45
(R95) | O3- | + | O3 |  |  | → | I-N DA | → | 3O2 | + | e |  |  | 3e-16 | 3e-16 | 3 × 10-16 |  | Sakyama |  | [18] | FALSE | FALSE |  | O3- + O3->3O2 + e | 3e-16
(R96) | NO- | + | M |  |  | → | I-N DA | → | NO | + | M | + | e | 2.4e-19 | 2.4e-19 | 2.40 × 10-19 |  | Sakyama |  | [20] | FALSE | FALSE |  | NO- + M->NO + M + e | 2.4e-19
(R97) | NO- | + | NO |  |  | → | I-N DA | → | 2NO | + | e |  |  | 5e-18 | 5e-18 | 5 × 10-18 |  | Sakyama |  | [20] | FALSE | FALSE |  | NO- + NO->2NO + e | 5e-18
(R98) | NO- | + | N2O |  |  | → | I-N DA | → | NO | + | N2O | + | e | 5.1e-18 | 5.1e-18 | 5.1 × 10-18 |  | Sakyama |  | [20] | FALSE | FALSE |  | NO- + N2O->NO + N2O + e | 5.1e-18
(R99) | NO- | + | H2 |  |  | → | I-N DA | → | NO | + | H2 | + | e | 2.3e-19 | 2.3e-19 | 2.3 × 10-19 |  | Sakyama |  | [20] | FALSE | FALSE |  | NO- + H2->NO + H2 + e | 2.3e-19
(R199) | O2- | + | O |  |  | → | I-N REC | → | O- | + | O2 |  |  | 3.3e-16 | 3.3e-16 | 3.3 × 10-16 |  | Sakyama |  | [11] | FALSE | FALSE | Verified | O2- + O->O- + O2 | 3.3e-16
(R101) | NO2- | + | N |  |  | → | I-N DA | → | N2 | + | O2 | + | e | 1e-18 | 1e-18 | 1 × 10-18 |  | Sakyama |  | [18] | FALSE | FALSE |  | NO2- + N->N2 + O2 + e | 1e-18
(R93) | O3- | + | O |  |  | → | I-N DA | → | 2O2 | + | e |  |  | 3e-16 | 3e-16 | 3 × 10-16 |  | Sakyama |  | [11] | FALSE | FALSE | Verified | O3- + O->2O2 + e | 3e-16
(R103) | NO3- | + | N |  |  | → | I-N DA | → | N2 | + | O3 | + | e | 1e-18 | 1e-18 | 1 × 10-18 |  | Sakyama |  | [18] | FALSE | FALSE |  | NO3- + N->N2 + O3 + e | 1e-18
(R104) | H- | + | O2 |  |  | → | I-N DA | → | HO2 | + | e |  |  | 1.2e-15 | 1.2e-15 | 1.2 × 10-15 |  | Sakyama |  | [19] | FALSE | FALSE | Verified | H- + O2->HO2 + e | 1.2e-15
(R105) | H- | + | H |  |  | → | I-N DA | → | H2 | + | e |  |  | 1.8e-15 | 1.8e-15 | 1.8 × 10-15 |  | Sakyama |  | [11] | FALSE | FALSE | Verified | H- + H->H2 + e | 1.8e-15
 | H- | + | e |  |  | → | I-e DA |  | H | + | 2e |  |  | 1.221829831e-13 | 1.221829831e-13 | 2.32 × 10-14 εe2 exp(-0.13/εe) |  |  |  |  | FALSE | FALSE |  | H- + e->H + 2e | 1.221829831e-13
(R185) | O4+ | + | O |  |  | → | I-N REC | → | O2+ | + | O3 |  |  | 3e-16 | 3e-16 | 3 × 10-16 |  | Sakyama |  | [11] | FALSE | FALSE | Verified | O4+ + O->O2+ + O3 | 3e-16
(R343) | N2+ | + | OH- |  |  | → | I-I NEUT | → | OH | + | N2 |  |  | 1.99007438e-13 | 1.99007438e-13 | 2 × 10-13 (300/Tg)0.5 |  | Sakyama |  | c | FALSE | FALSE |  | N2+ + OH-->OH + N2 | 1.99007438e-13
(R362) | N2O+ | + | OH- |  |  | → | I-I NEUT | → | OH | + | N2O |  |  | 1.99007438e-13 | 1.99007438e-13 | 2 × 10-13 (300/Tg)0.5 |  | Sakyama |  | [8] | FALSE | FALSE |  | N2O+ + OH-->OH + N2O | 1.99007438e-13
(R401) | NO+ | + | OH- |  |  | → | I-I NEUT | → | OH | + | NO |  |  | 1.99007438e-13 | 1.99007438e-13 | 2 × 10-13 (300/Tg)0.5 |  | Sakyama |  | c | FALSE | FALSE |  | NO+ + OH-->OH + NO | 1.99007438e-13
(R318) | N+ | + | NO2- |  |  | → | I-I NEUT | → | NO2 | + | N |  |  | 1.99007438e-13 | 1.99007438e-13 | 2 × 10-13 (300/Tg)0.5 |  | Sakyama |  | [9] | FALSE | FALSE |  | N+ + NO2-->NO2 + N | 1.99007438e-13
(R319) | N+ | + | NO3- |  |  | → | I-I NEUT | → | NO3 | + | N |  |  | 1.99007438e-13 | 1.99007438e-13 | 2 × 10-13 (300/Tg)0.5 |  | Sakyama |  | [9] | FALSE | TRUE |  | N+ + NO3-->NO3 + N | 1.99007438e-13
(R420) | NO2+ | + | OH- |  |  | → | I-I NEUT | → | OH | + | NO2 |  |  | 1.99007438e-13 | 1.99007438e-13 | 2 × 10-13 (300/Tg)0.5 |  | Sakyama |  | c | FALSE | FALSE |  | NO2+ + OH-->OH + NO2 | 1.99007438e-13
(R321) | N+ | + | O2- |  |  | → | I-I NEUT | → | O2 | + | N |  |  | 1.99007438e-13 | 1.99007438e-13 | 2 × 10-13 (300/Tg)0.5 |  | Sakyama |  | [8] | FALSE | FALSE |  | N+ + O2-->O2 + N | 1.99007438e-13
(R322) | N+ | + | O3- |  |  | → | I-I NEUT | → | O3 | + | N |  |  | 1.99007438e-13 | 1.99007438e-13 | 2 × 10-13 (300/Tg)0.5 |  | Sakyama |  | [8] | FALSE | FALSE |  | N+ + O3-->O3 + N | 1.99007438e-13
(R324) | N+ | + | H- |  |  | → | I-I NEUT | → | N | + | H |  |  | 1.99007438e-13 | 1.99007438e-13 | 2 × 10-13 (300/Tg)0.5 |  | Sakyama |  | c | FALSE | FALSE |  | N+ + H-->N + H | 1.99007438e-13
(R431) | H+ | + | OH- |  |  | → | I-I NEUT | → | OH | + | H |  |  | 1.99007438e-13 | 1.99007438e-13 | 2 × 10-13 (300/Tg)0.5 |  | Sakyama |  | c | FALSE | FALSE |  | H+ + OH-->OH + H | 1.99007438e-13
(R323) | N+ | + | O4- |  |  | → | I-I NEUT | → | 2O2 | + | N |  |  | 1e-13 | 1e-13 | 1 × 10-13 |  | Sakyama |  | [9] | FALSE | FALSE |  | N+ + O4-->2O2 + N | 1e-13
(R124) | N+ | + | H2O |  |  | → | I-N REC | → | H2O+ | + | N |  |  | 1.19e-15 | 1.19e-15 | 1.19 × 10-15 |  | Sakyama |  | [25] | FALSE | FALSE |  | N+ + H2O->H2O+ + N | 1.19e-15
(R111) | N+ | + | NO |  |  | → | I-N REC | → | NO+ | + | N |  |  | 8e-16 | 4.72e-16 | 8 × 10-16 |  | Sakyama |  | [11] | FALSE | FALSE | Verified | N+ + NO->NO+ + N | 8e-16
(R110) | N+ | + | N2O |  |  | → | I-N REC | → | NO+ | + | N2 |  |  | 5.5e-16 | 5.5e-16 | 5.5 × 10-16 |  | Sakyama |  | [11] | FALSE | FALSE | Verified | N+ + N2O->NO+ + N2 | 5.5e-16
(R115) | N+ | + | NO2 |  |  | → | I-N REC | → | NO+ | + | NO |  |  | 5e-16 | 5e-16 | 5 × 10-16 |  | Sakyama |  | [23] | FALSE | FALSE |  | N+ + NO2->NO+ + NO | 5e-16
(R121) | N+ | + | O3 |  |  | → | I-N REC | → | NO+ | + | O2 |  |  | 5e-16 | 5e-16 | 5 × 10-16 |  | Sakyama |  | [11] | FALSE | FALSE | Verified | N+ + O3->NO+ + O2 | 5e-16
(R109) | N+ | + | N2 | + | O2 | → | I-N REC (TBA) | → | N3+ | + | O2 |  |  | 4.495083884e-16 | 1.242e-15 | 1.7 × 10-41(300/Teff)2.1 |  | Sakyama |  | [11] | FALSE | FALSE | Verified | N+ + N2 + O2->N3+ + O2 | 4.495083884e-16
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

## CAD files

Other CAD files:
discharge_chambers/3d_rotaing_gliding_arc/3d magnetic gliding arc v4.f3d
discharge_chambers/3d_rotaing_gliding_arc/3d magnetic gliding arc v4.f3z
discharge_chambers/barrier_discharge/barrier_discharge.f3d
discharge_chambers/glinding_arc/glinding_arc.f3d
discharge_chambers/spiral gliding arc/Gliding Arc Spiral v10.f3d
discharge_chambers/spiral gliding arc/Gliding Arc Spiral v17.f3d
discharge_chambers/surface_barrier_discharge/surface_barrier_discharge.f3d
power_electronics/transformer/High-Voltage_Transformer.f3d

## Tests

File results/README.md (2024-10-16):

# Achieved results

## DBD 50kHZ
We conducted tests on bacterial contaminants using a 4-liter tank with a circulating pump FIP 3200-24 and a discharge chamber at a discharge frequency of approximately 50 kHz. (This frequency corresponds to the previous version of the power electronics; in the next stage, we plan to work at a frequency of 500-1000 kHz).
For the tests, we added a mix of PA, SA, and E. coli bacteria to the water at a concentration of 1000 CFU/ml, thoroughly mixed it, and then activated the [discharge chamber](/discharge_chambers/barrier_discharge).

[Photo of results](50kHZ_DBD_FIP3200-24.jpg)

## Gliding Arc 500kHZ
Details [here](./500_gliding_arc/)

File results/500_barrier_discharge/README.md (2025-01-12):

**Current Results:**
- **Energy consumption:** 220W discharge + 100W pump
- **Treatment time:** 3 min
- **Nitrate:** 25 ppm 
- **Nitrite:** 5 ppm 

**Note:** Results significantly exceed initial expectations - potential measurement verification needed. Planning to recheck with new stable discharge chamber (Jan 13-20, 2024).

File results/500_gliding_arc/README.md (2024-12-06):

## Gliding Arc 500kHz

**Experimental Setup**

[Pump](https://www.amazon.de/-/en/dp/B0DDK7QR6L?ref=ppx_yo2ov_dt_b_fed_asin_title)  
- Flow rate: 10 L/min  
- Pressure: 10 bar  

[Coil](/power_electronics/transformer)  
- Core T60006-L2090-W518
- 3 turns primary winding - litz 3x20x0.2
- 130 turns secondary winding - 0.3 mm Enamelled copper wire
- L1 ~ 190 μH, L2 ~ 190 mH, k > 0.99 (estimate, as it is hard to measure L1/L2 in 500 kHz frequency)
- Cp = 10 pF (measured by 10 points of LC resonaut circuit)
- Cw = 1.6 pF (measured by PeakTech 2170)
- C1 = 22 nF, Cd = 1.6 pF (measured by PeakTech 2170)

[Discharge Chamber](/discharge_chambers/gliding_arc)

**Results**

[Video](glinding_arc_air.MOV) how gliding arc works in dry air

DC Voltage ~19V, DC Current 6.4A, Power ~ 120 W

Resonaunt frequency 540 kHz (close to equivalent circut prediction)

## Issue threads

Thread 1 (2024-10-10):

Low coupling coefficient of transformer and low transformer ratio

minstrel1983, 2024-10-10:
The current transformer design should ensure a coupling coefficient of approximately 0.8-0.9, but current measurements show only 0.5.

Hypothesis:

Stray inductance in the primary winding is likely due to a questionable design of the primary windings.

Outcomes:
1. Overheating C1 battery, i.e. loosing energy
2. High load on H-Brindge and promary winding due to high-volatage ~1 kV in primary windings

minstrel1983, 2024-10-15:
Problem is clear now - parasitic inductance of wires.

Parallel winding in the primary inductive was bad idea.

New transformer desing coming soon.

minstrel1983, 2024-10-16:
Alternative solution - bring transfer as closest as possible to H-Bridge. Max distance - 5-10 cm.

minstrel1983, 2024-10-20:
Current transformer design doesn't fit.

Current transformer ratio definetely not enough.

New transformer design wto be ready by the middle of November

minstrel1983, 2024-10-23:
New transformer design uploaded https://github.com/kinetikalab/project_aetheris/blob/main/power_electronics/transformer/README.md

To be tested next week in real conditions.

minstrel1983, 2024-12-02:
Transformer design updated
https://github.com/kinetikalab/project_aetheris/blob/main/power_electronics/transformer/README.md

The problem was with parasitic capacity. Now it fixed. New transformer has very low parasitic capacity ~10 pF.

Tested in discharge - works perfect.

Closed 2024-12-02.

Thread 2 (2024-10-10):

Ejector design - Fluid Reverse

minstrel1983, 2024-10-10:
Fluid reverse in ejector

Hypothesis:
1. Incorrect formulas used in the calculation of ejector parameters.
2. Poor manufacturing quality—3D printing doesn't provide acceptable tolerances.
3. The design itself makes it difficult to ensure central symmetry.

minstrel1983, 2024-10-11:
Problem with the pump.

High quality pump with 8+ Bar and 10+ L/min is required

Closed 2024-10-20.

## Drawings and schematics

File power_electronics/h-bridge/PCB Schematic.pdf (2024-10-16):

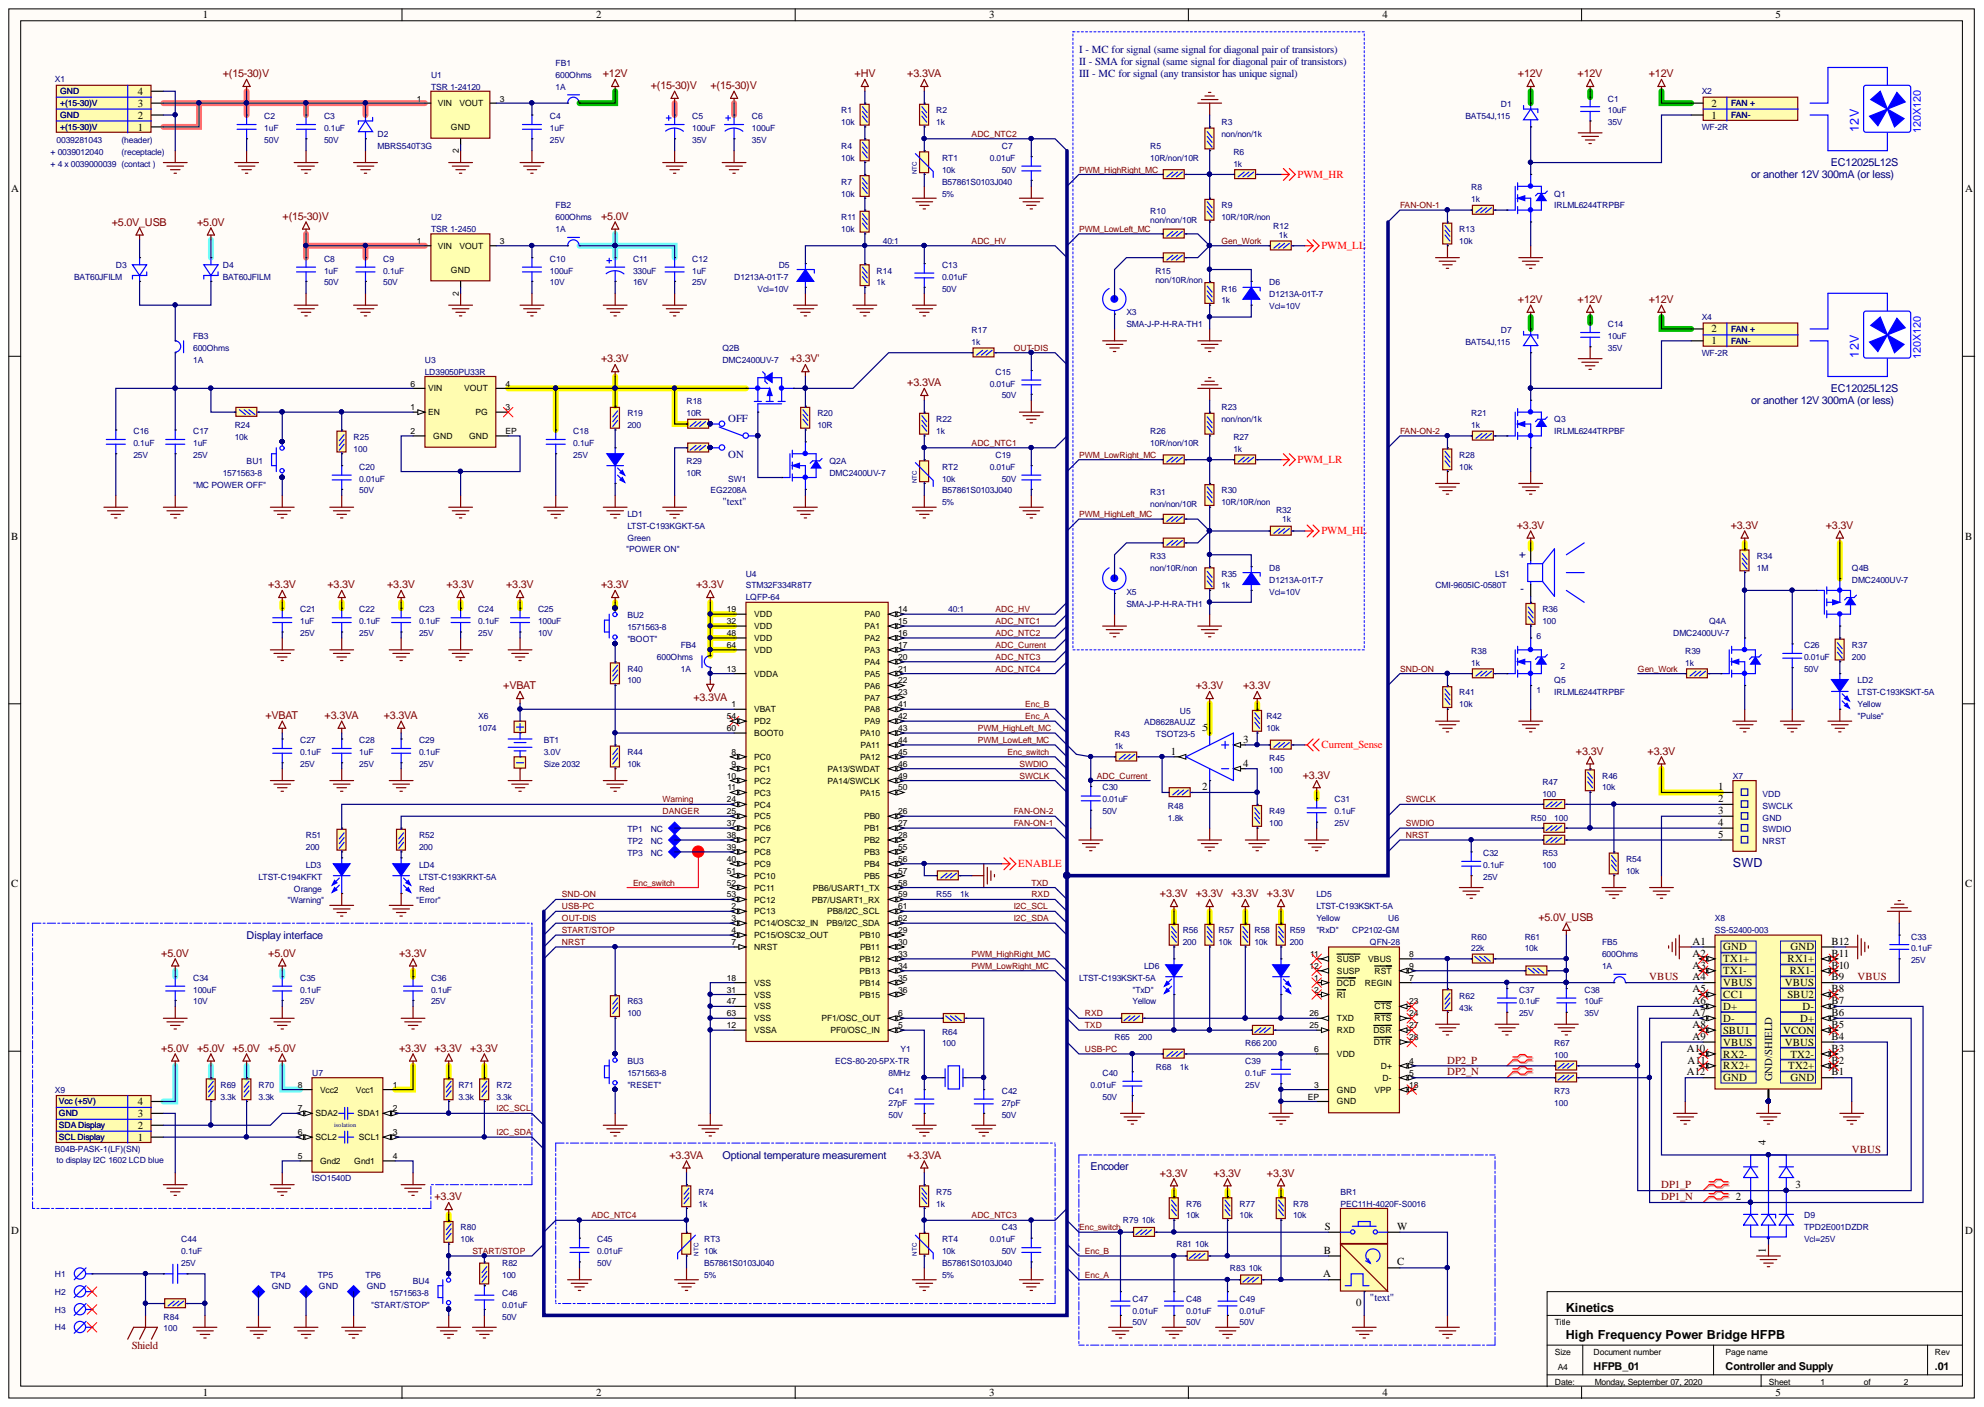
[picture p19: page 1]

I - MC for signal (same signal for diagonal pair of transistors)
II - SMA for signal (same signal for diagonal pair of transistors)
III - MC for signal (any transistor has unique signal)

or another 12V 300mA (or less)

2 | FAN +
1 | FAN-

Vcc (+5V) | 4
GND | 3
SDA Display | 2
SCL Display | 1

B04B-PASK-1(LF)(SN)
to display I2C 1602 LCD blue

+3.3VA | Optional temperature measurement +3.3VA

Title
High Frequency Power Bridge HFPB

Size A4 | Document number HFPB_01 | Page name Controller and Supply | Rev .01

Date: Monday, September 07, 2020 | Sheet 1 of 2

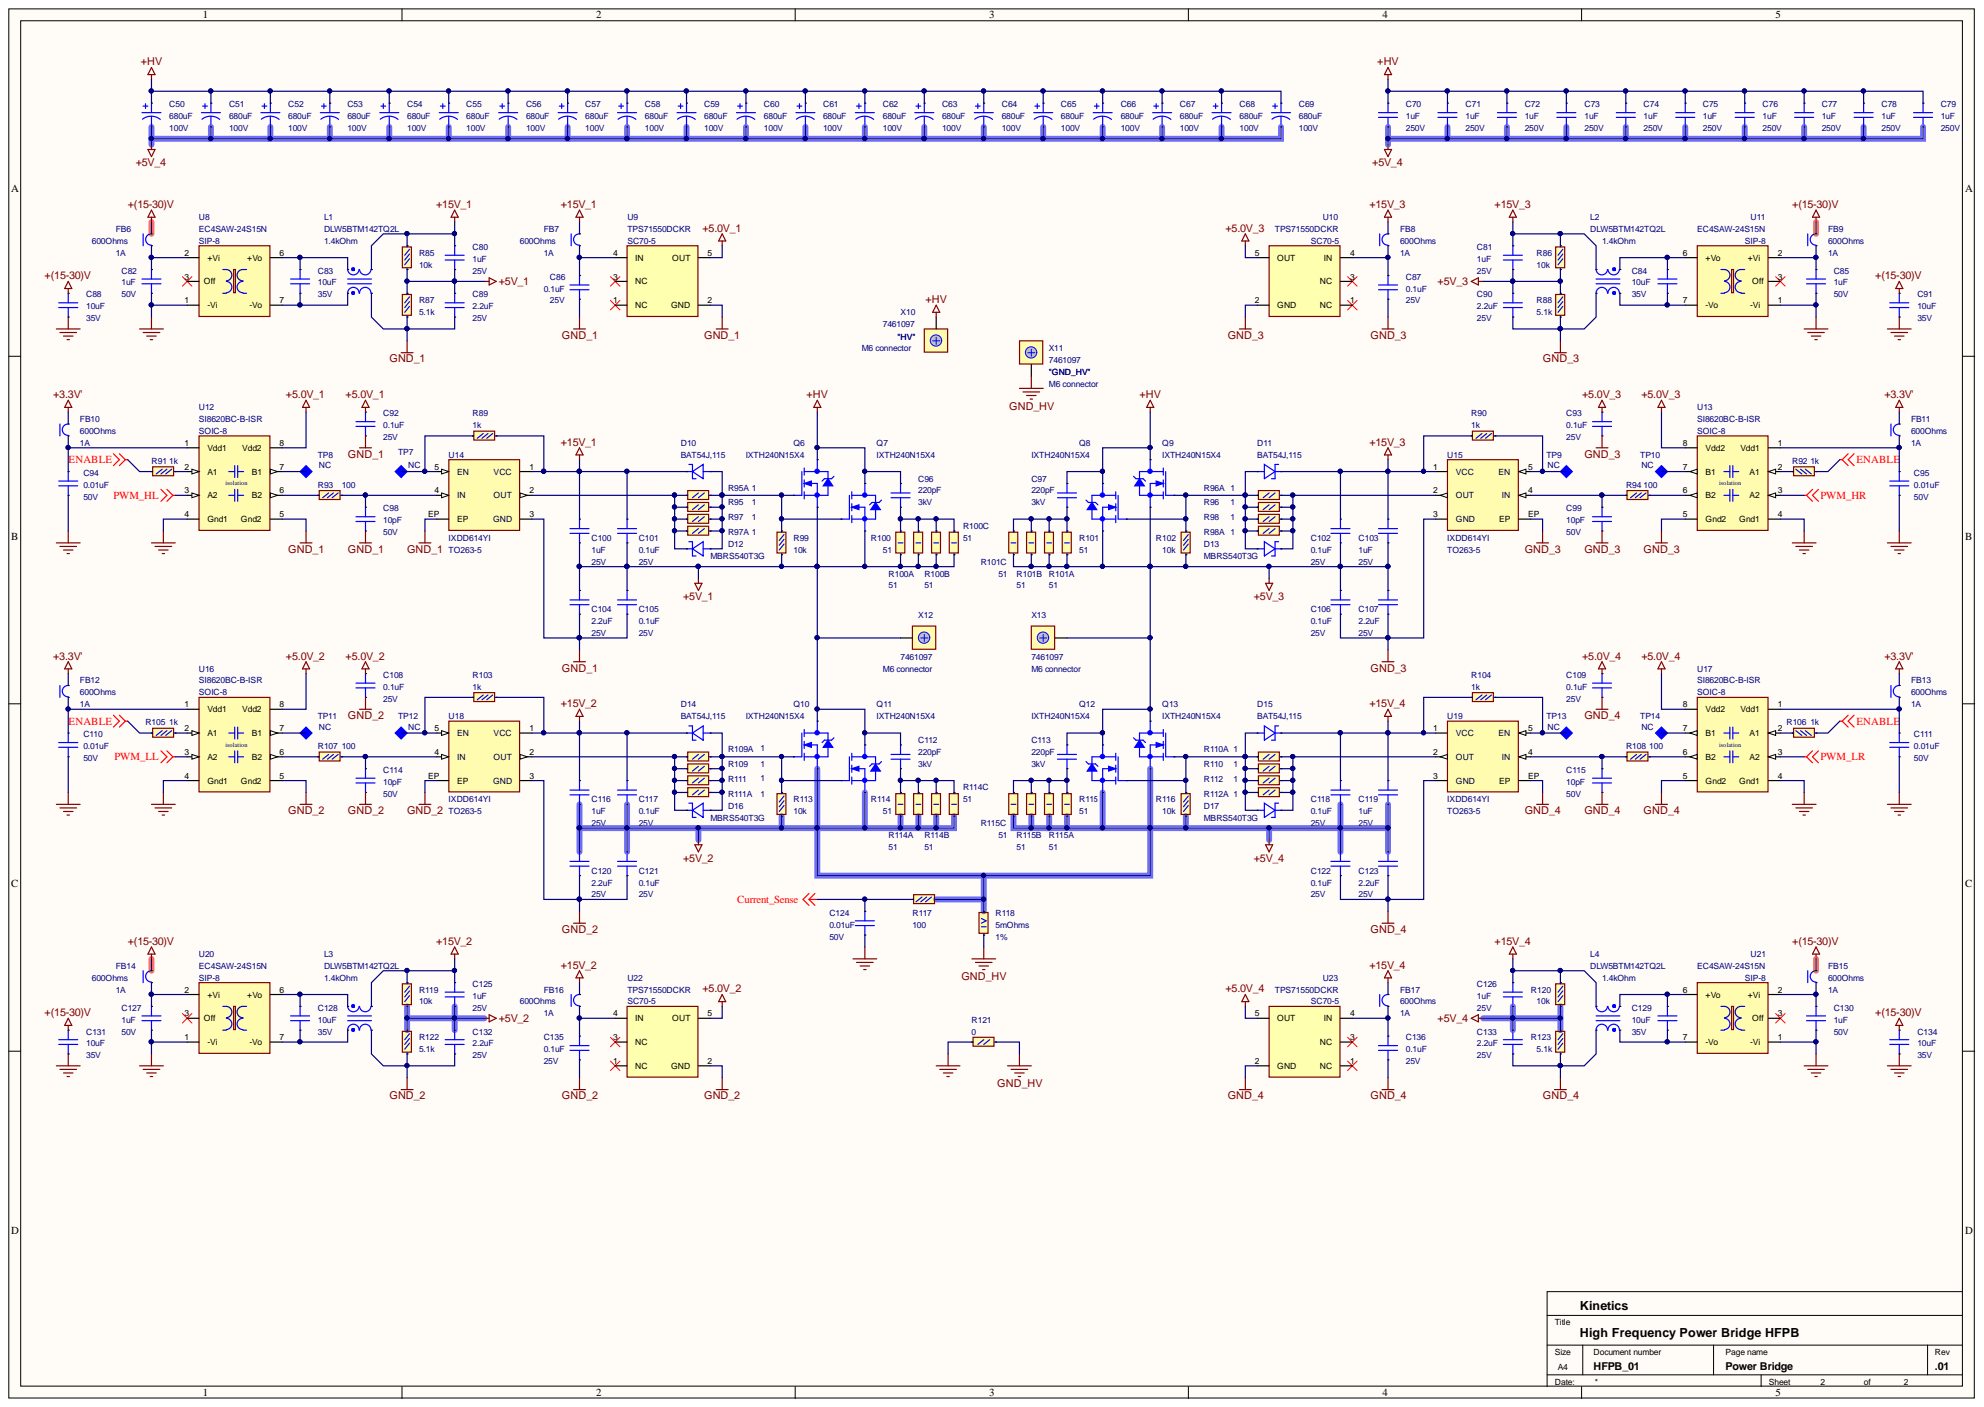
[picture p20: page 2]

Title
High Frequency Power Bridge HFPB

Size A4 | Document number HFPB_01 | Page name Power Bridge | Rev .01

Date: * | Sheet 2 of 2

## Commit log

2024-10-03 first commit - uploading initial data
    [BOM.xlsx, HFPB_01, PAGE-1.SchDoc, HFPB_01, PAGE-2.SchDoc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]
2024-10-06 Update README.md
    Add couple of comments about NO2-/NO3 residues
2024-10-06 important comment about litz wire
2024-10-07 small changes in README.md - explanation role of HO redicals
    [3d magnetic gliding arc v4.f3d, 3d magnetic gliding arc v4.f3z]
2024-10-11 Couple of comments about ejector
2024-10-16 add PCB schematic and H-Bridge step file
2024-10-16 changed equivalent circuit - added parasitic capacity of the secondary winding
2024-10-23 new design of transformer
    [housing.stl, resonant_transformer.f3d]
2024-10-29 new coil design 3d model
    [New_Coil_Form.f3d]
2024-12-01 New transformer design
    [High-Voltage Transformer.f3d, New_Coil_Form.f3d, ReactionDB.xlsx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]
2025-01-11 new barrier discharge chamber
2025-02-06 spiral gliding arc
    [Gliding Arc Spiral v10.f3d, Nitrogen_Estimations.xlsx, ReactionDB-1.xlsx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]
2025-02-12 some small changes
    [High-Voltage Transformer.f3d, High-Voltage_Transformer.f3d, Nitrogen_Estimations.xlsx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]
2025-06-14 Spiral Arc 17
    [Gliding Arc Spiral v17.f3d, ReactionDB-1.xlsx]
2026-01-23 dischange chambers update
